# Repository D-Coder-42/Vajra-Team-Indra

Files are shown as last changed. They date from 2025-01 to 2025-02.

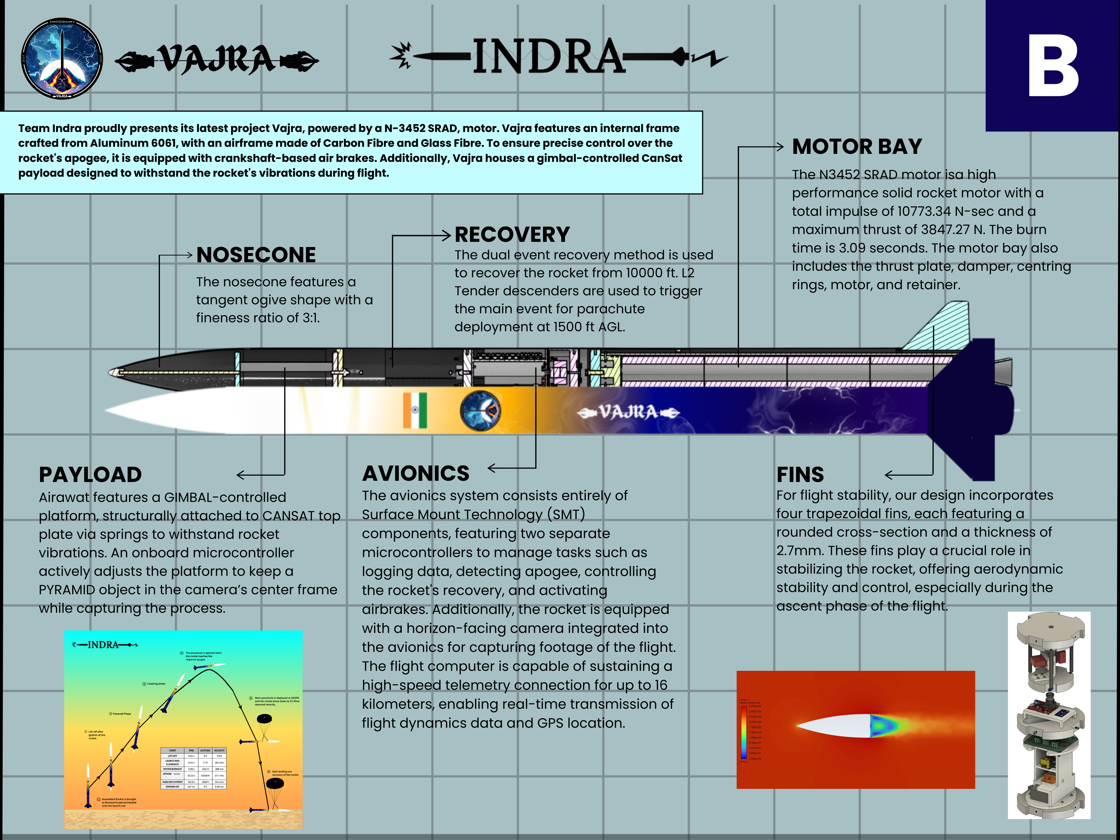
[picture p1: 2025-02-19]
Management/Poster Session.png

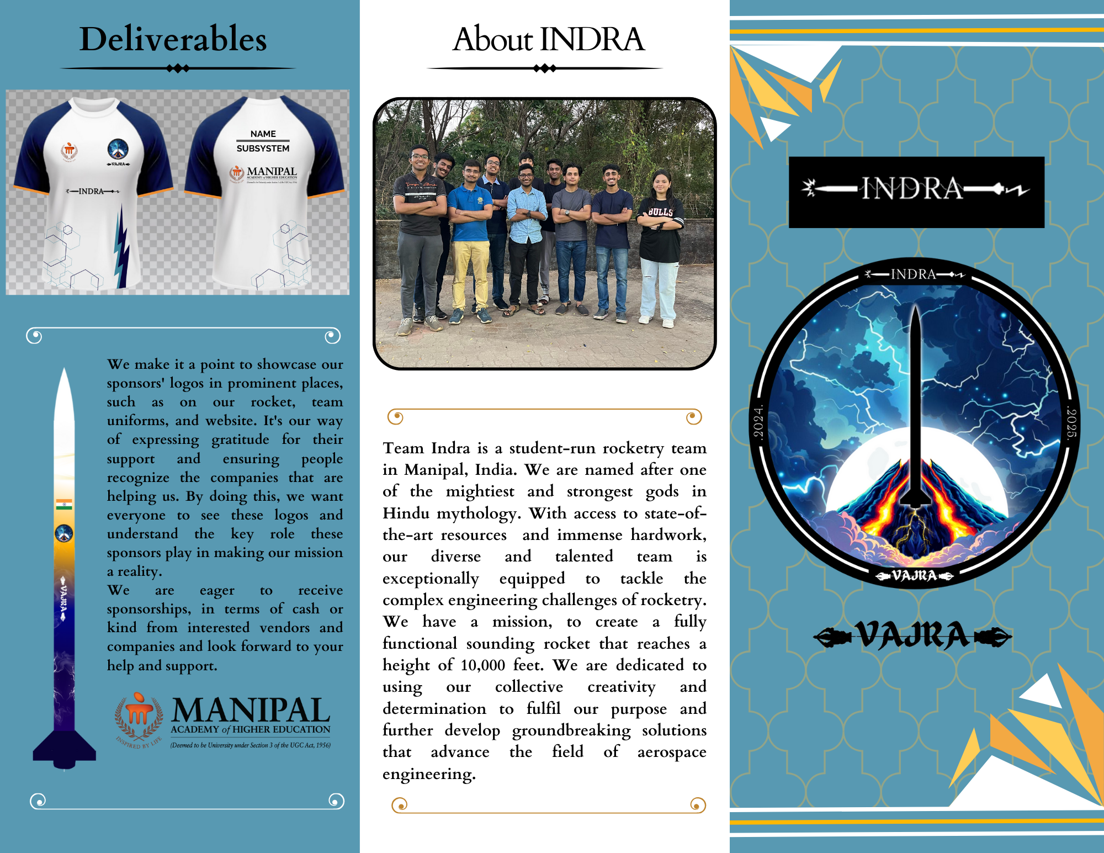
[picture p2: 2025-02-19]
Management/Brochure (Page 1).png

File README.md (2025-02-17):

# Project Vajra
## By Team Indra

### Table of Contents
- [Team Members](#team-members)
- [Abstract](#abstract)
- [Introduction](#introduction)
- [Goals](#goals)

### Team Members
- **Shaurya Mittal** - Aerodynamics Member
- **Shaunak Purkayastha** - Propulsion Member
- **Tushit Chatterjee** - Structures Member
- **Krishanu Dey** - Avionics Member
- **Dhruv Phalod** - Avionics Member
- **Vanshdeep Trivedi** - Avionics Member
- **Mutra Sai Tharun** - Payload Member
- **Rudra Rajpurohit** - Payload Member
- **Swaraa Sule** - Management Member
- **Adithya Adiga** - Management Member

### Project Abstract
Team Indra’s rocket, Vajra, is powered by an N3452 N-class SRAD rocket motor. Its internal frame is made from Aluminum 6061, and the aerodynamic structure combines Carbon Fibre and Glass Fibre for optimal performance. The nosecone houses a CanSat payload with a GIMBAL-controlled platform, attached via springs to withstand rocket vibrations. An onboard microcontroller ensures the platform is positioned to keep a PYRAMID object aligned with the camera’s center for tracking the entire flight. The avionics use Surface Mount Technology (SMT) components, with two microcontrollers handling tasks like data logging, apogee detection, recovery control, and airbrake activation. The flight computer supports real-time telemetry up to 16 kilometers, transmitting flight dynamics and GPS data.

### Team Introduction
Team Indra is a student-run rocketry team based in Manipal, India. We are named after one of the mightiest and strongest gods in Hindu mythology. With access to state-of-the-art resources and immense hard work, our diverse and talented team is exceptionally equipped to tackle the complex engineering challenges of rocketry. Our mission is to create a fully functional sounding rocket that reaches a height of 10,000 feet. We are dedicated to using our collective creativity and determination to fulfill our purpose and further develop groundbreaking solutions that advance the field of aerospace engineering.

### Goals
- Develop a fully functional sounding rocket.
- Achieve a flight altitude of 10,000 feet.
- Innovate in the fields of aerodynamics, propulsion, and avionics.

###
All codes and files for Team B of thrustMIT subscale are included in this repository.

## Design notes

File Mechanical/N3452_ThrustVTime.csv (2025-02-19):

Time(s) | Thrust(N)
0 | 0
0.03 | 2930.23055
0.06 | 2946.55281
0.09 | 2962.75934
0.12 | 2978.84899
0.15 | 2994.82061
0.18 | 3010.6731
0.21 | 3026.40532
0.24 | 3042.01619
0.27 | 3057.5046
0.3 | 3072.86948
0.33 | 3088.10975
0.36 | 3103.22435
0.39 | 3118.21222
0.42 | 3133.07234
0.45 | 3147.80367
0.48 | 3162.40519
0.51 | 3176.87589
0.54 | 3191.21478
0.57 | 3205.42087
0.6 | 3219.49318
0.63 | 3233.43075
0.66 | 3247.23263
0.69 | 3260.89786
0.72 | 3274.42552
0.75 | 3287.81469
0.78 | 3301.06445
0.81 | 3314.17391
0.84 | 3327.14217
0.87 | 3339.96836
0.9 | 3352.6516
0.93 | 3365.19104
0.96 | 3377.58584
0.99 | 3389.83515
1.02 | 3401.93816
1.05 | 3413.89405
1.08 | 3425.70201
1.11 | 3437.36127
1.14 | 3448.87102
1.17 | 3460.23051
1.2 | 3471.43898
1.23 | 3482.49568
1.26 | 3493.39986
1.29 | 3504.15081
1.32 | 3514.74781
1.35 | 3525.19016
1.38 | 3535.47716
1.41 | 3545.60812
1.44 | 3555.58239
1.47 | 3565.3993
1.5 | 3575.05819
1.53 | 3584.55844
1.56 | 3593.89941
1.59 | 3603.0805
1.62 | 3612.10109
1.65 | 3620.96058
1.68 | 3629.65841
1.71 | 3638.19399
1.74 | 3646.56677
1.77 | 3654.7762
1.8 | 3662.82174
1.83 | 3670.70285
1.86 | 3678.41904
1.89 | 3685.96978
1.92 | 3693.35459
1.95 | 3700.57299
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

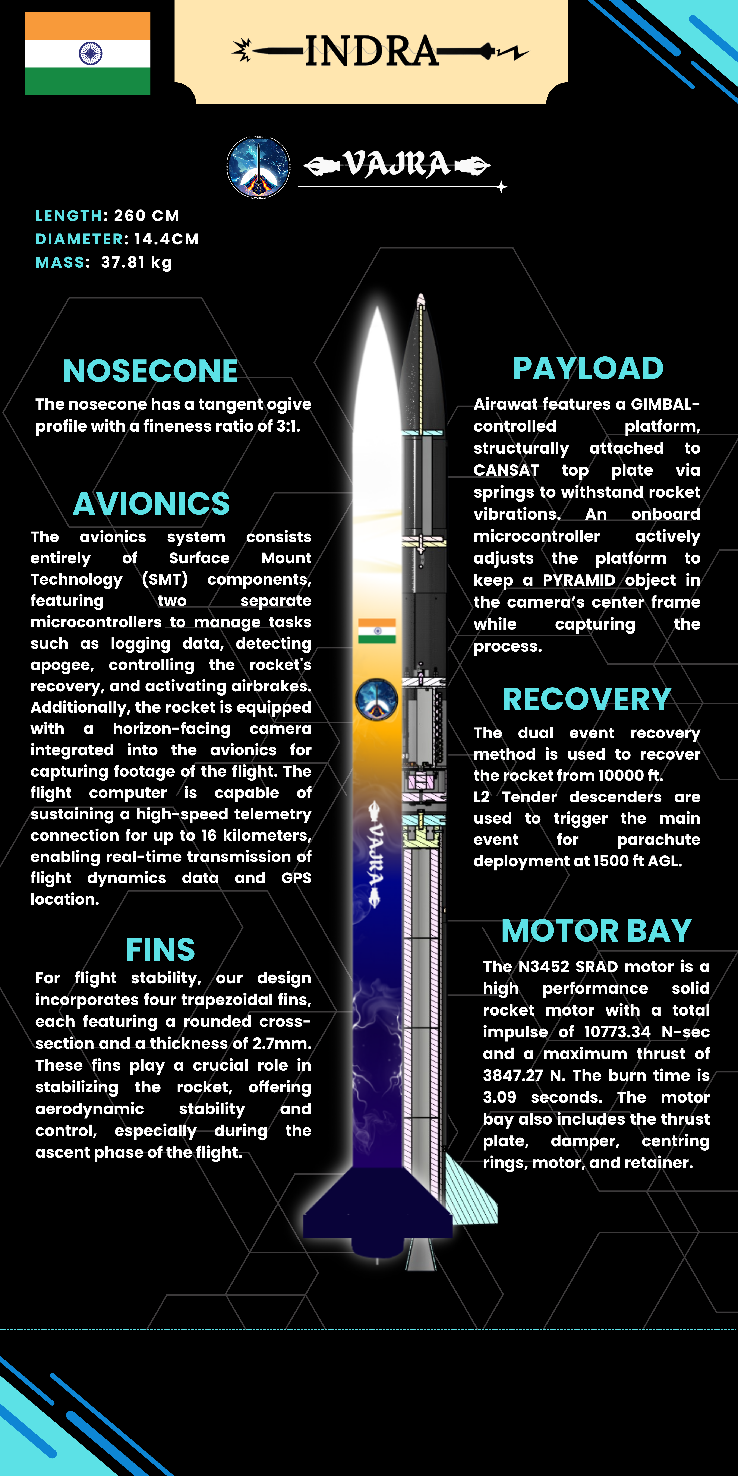
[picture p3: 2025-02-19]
Management/Con-Ops Poster.png

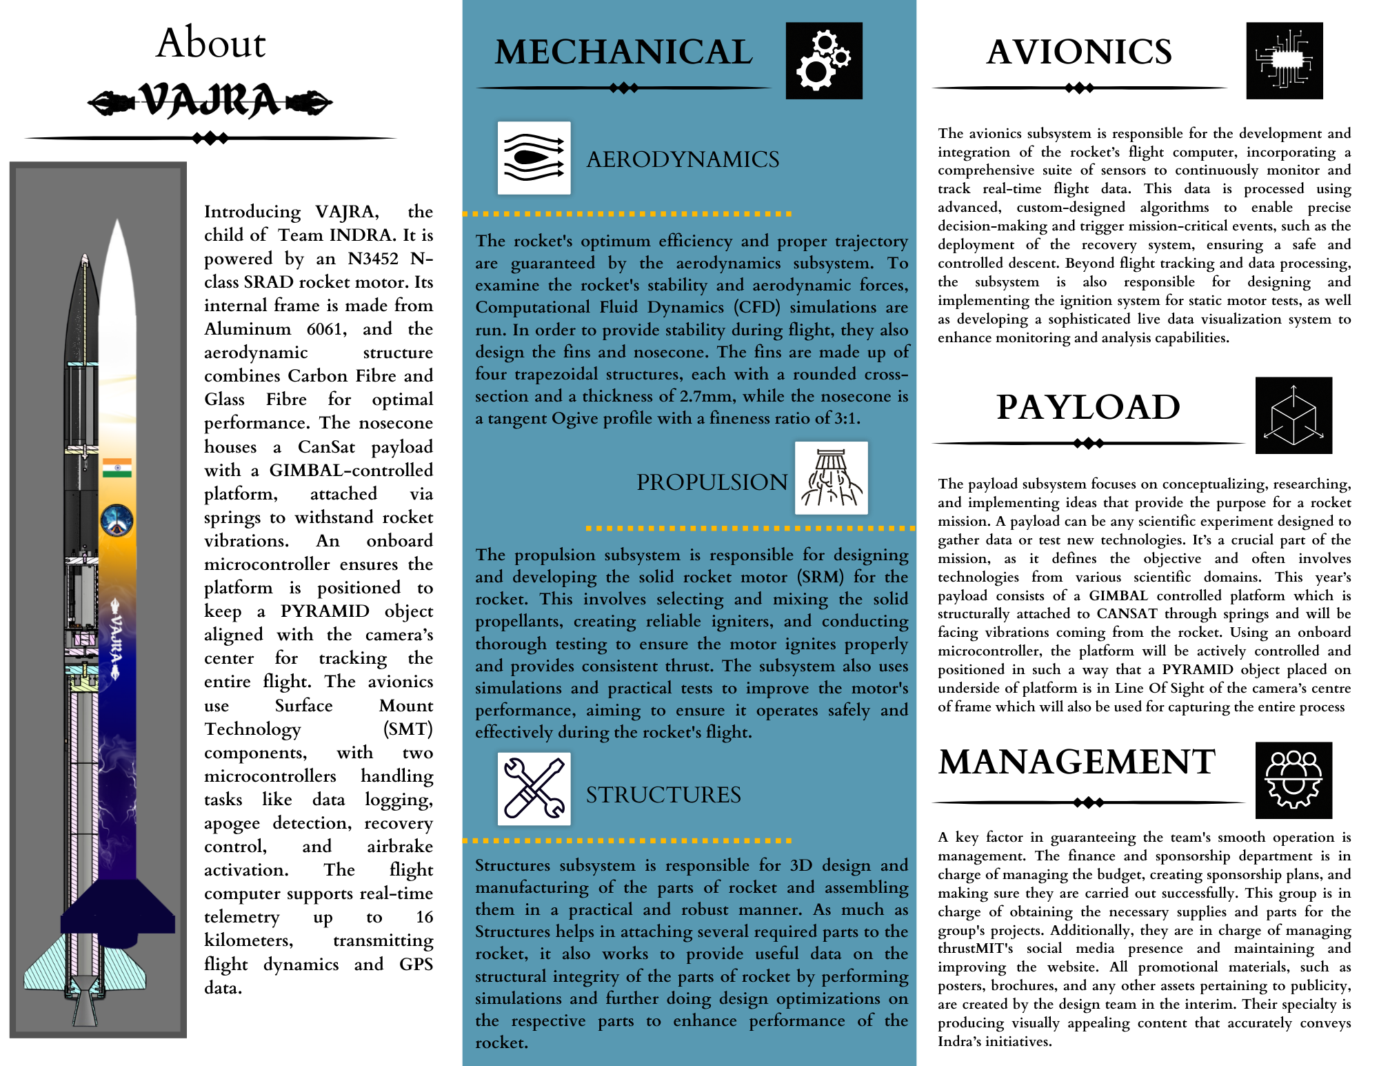
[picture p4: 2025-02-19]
Management/Brochure (Page 2).png

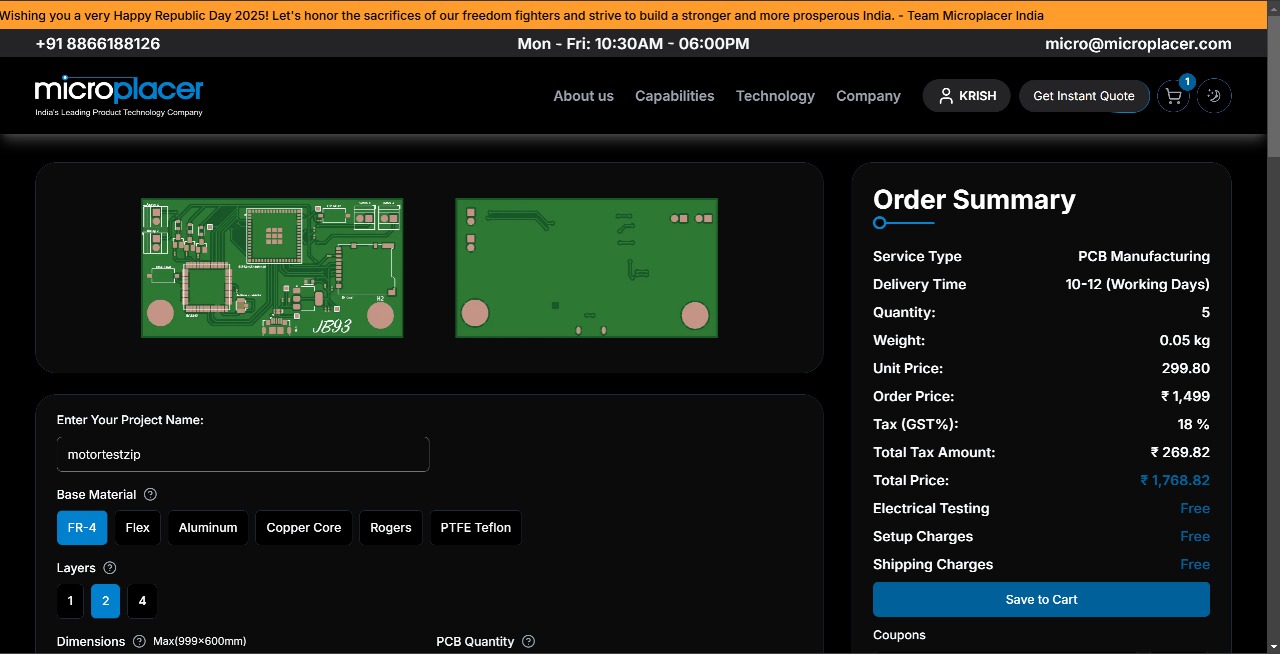
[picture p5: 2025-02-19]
Avionics/Ignition System PCB/JB93_QUOTATION.jpg

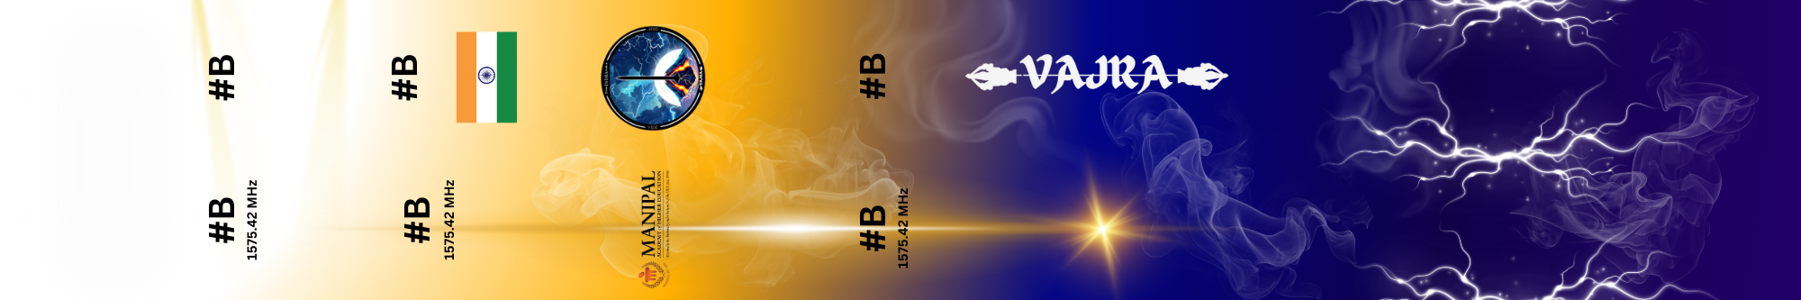
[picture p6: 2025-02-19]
Management/Rocket Decal.png

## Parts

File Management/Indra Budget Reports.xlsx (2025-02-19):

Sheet: Budget Report
ltems | Vendor Name | Quantity Required | Subsystem | Unit Price (INR) | Total Amount (INR)
Kevlar Shock Cord | https://www.apogeerockets.com/Building_Supplies/Parachutes_Recovery_Equipment/Shock_Cord/Kevlar_Cord_300 | 22 units | Aerodynamics | 352 | 7744
24" Compact Elliptical Parachute | https://shop.fruitychutes.com/collections/parachutes/products/24-compact-elliptical-parachute-2-1lb-20fps | 1 unit | Aerodynamics | 6828 | 6828
Iris UltraLight 66" Parachute | https://shop.fruitychutes.com/collections/iris-ultralight-parachutes/products/iris-66-ultra-light-parachute-13-6lb-15fps | 1 unit | Aerodynamics | 29708 | 29708
1515 Rail Buttons | https://shop.fruitychutes.com/products/1515-rail-button-pair-of-2 | 1 Pair | Aerodynamics | 350 | 350
L2 tender Descenders | https://www.apogeerockets.com/Building-Supplies/Recovery-Equipment/Tether-Release-Devices/TD-2-Tether-and-Release-Device | 2 | Aerodynamics | 9957 | 19914
MPXV5100DP | https://in.element14.com/nxp/mpxv5100dp/pressure-sensor-dual-14-5-psi/dp/1608912 | 2 | Avionics | 1462 | 2924
ESP32 S3 WROOM 1U | https://robu.in/product/espressif-esp32-s3-wroom-1u-n16r8-module/ | 2 | Avionics | 299 | 598
ESP32 S3 MINI 1U | https://www.digikey.in/en/products/detail/espressif-systems/ESP32-S3-MINI-1U-N8/17728863 | 4 | Avionics | 267.44 | 1069.76
IIM-42653 | https://www.digikey.in/en/products/detail/tdk-invensense/IIM-42653/22477277 | 2 | Avionics | 489.8 | 979.6
LPS22HHTR | https://robu.in/product/stmicroelectronics-lps22hhtr26kpa126kpa-1-7v3-6v-40%e2%84%8385%e2%84%83/ | 2 | Avionics | 312 | 624
D3V3XA4B10LP | https://www.digikey.in/en/products/detail/diodes-incorporated/D3V3XA4B10LP-7/10295141 | 6 | Avionics | 24.16 | 144.96
Micro SD connector SMD | https://in.element14.com/hirose-hrs/dm3bt-dsf-pejs/connector-micro-sd-push-push-smt/dp/1764375 | 4 | Avionics | 194.81 | 779.24
AMS11177-3.3V | https://robu.in/product/ams1117-3-3v-1a-sot-223-voltage-regulator-ic-pack-of-5-ics/ | 10 | Avionics | 11 | 110
M20050-1 | https://www.digikey.in/en/products/detail/antenova/M20050-1/7931499 | 2 | Avionics | 2037.84 | 4075.68
USB port | https://in.element14.com/gct-global-connector-technology/usb3076-30-a/micro-usb-2-0-type-b-receptacle/dp/2443117 | 6 | Avionics | 59.28 | 355.68
AMS1117-5V | https://robu.in/product/ams1117-5-0v-1a-sot-223-voltage-regulator-ic-pack-of-5-ics/ | 5 | Avionics | 5.2 | 26
Solder Kit | https://robu.in/product/plusivo-soldering-kit-with-diagonal-wire-cutter/ | 1 | Avionics | 1365 | 1365
IRLR7843TRPBF | https://robu.in/product/irlr7843trpbf-mosfet/ | 4 | Avionics | 128 | 512
RYLR993 | https://robu.in/product/reyax-rylr993-868-915mhz-lorawan-transceiver-module/ | 4 | Avionics | 1099 | 4396
Camera | https://robu.in/product/runcam-split-3-nano-hd-fpv-camera/ | 1 | Avionics | 5642 | 5642
LEDs | https://robu.in/product/0805-surface-mount-led-red-50-pcs/ | 10 | Avionics | 2 | 20
LEDs | https://robu.in/product/0805-surface-mount-led-green-50-pcs/ | 10 | Avionics | 2 | 20
LEDs | https://robu.in/product/0805-surface-mount-led-blue-50-pcs/ | 10 | Avionics | 2 | 20
Push button | https://robu.in/product/362-5mm-tactile-push-button-switch-20pcs/ | 6 | Avionics | 10 | 60
Desolder wick | https://robu.in/product/desoldering-wick-1-5m-100-copper/ | 1 | Avionics | 149 | 149
Pyro Batteries | https://robu.in/product/molicel-inr18650-p28a-2800mah-13c-lithium-ion-battery/ | 4 | Avionics | 434 | 1736
Main batteries | https://robu.in/product/molicel-inr-18650-m35a-3-6v-3500mah-3c-li-ion-battery/ | 7 | Avionics | 499 | 3493
Featherweight GPS (incl Shipping + customs) | https://www.featherweightaltimeters.com/store/p22/Featherweight_GPS_Tracker_%28upd%29.html | 1 | Avionics | 31547.99 | 31547.99
EasyMini (incl Shipping + Customs) | https://www.apogeerockets.com/Electronics-Payloads/Dual-Deployment/EasyMini | 1 | Avionics | 13015.48 | 13015.48
2 x 1 Battery holders | https://robu.in/product/18650-dual-smd-smt-high-quality-single-battery-holder/ | 3 | Avionics | 76 | 228
1 x 1 Battery holders | https://robu.in/product/18650-battery-holder-smd-smt/ | 3 | Avionics | 31 | 93
SMA to UFL.R connector | https://robu.in/product/lwc-ca-sma-jack-bh-st-ufl-1-13mm-rf-cable-assemblies-15cm/?gad_source=1 | 3 | Avionics | 69 | 207
900MHz Antenna | https://robu.in/product/698-960-mhz-1710-2690-mhz-5dbi-gain-dual-band-3g-4g-lte-antenna/?gad_source=1 | 3 | Avionics | 199 | 597
Digital Multimeter | https://robu.in/product/htc-830l-digital-multimeter/ | 1 | Avionics | 585 | 585
Prototyping board | https://robu.in/product/9-x-15-cm-universal-pcb-prototype-board-single-sided-2-54mm-hole-pitch/ | 1 | Avionics | 80 | 80
Pressure Transducer | https://robu.in/product/30mpa-stainless-steel-pressure-transducer-sensor-copy/ | 1 | Avionics | 2585 | 2585
IRLB8314 | https://in.element14.com/infineon/irlb8314pbf/mosfet-n-channel-30v-171a-to-220ab/dp/2617411 | 5 | Avionics | 111.05 | 555.25
Servo | https://probots.co.in/servo-ds5160-60kg-270-degrees-high-torque-high-speed-digital-steering-gear.html | 1 | Avionics | 4999 | 4999
22AWG Wires (Red) | https://robu.in/product/high-quality-ultra-flexible-22awg-silicone-wire-1000m-red/ | 15 | Avionics | 18 | 270
100 nF Capacitor | https://robu.in/product/c2012x7r1h104kt0j0n-tdk-50v-100nf-x7r%C2%B110-0805-multilayer-ceramic-capacitors-mlcc-smd-smt-rohs/ | 36 | Avionics | 2 | 72
10nF Capacitor | https://robu.in/product/c2012c0g1h103jt000n-tdk-50v-10nf-c0g%C2%B15-0805-multilayer-ceramic-capacitors-mlcc-smd-smt-rohs/ | 2 | Avionics | 4 | 8
10uF Capacitor | https://robu.in/product/0805b106k160nt-fh-16v-10uf-x7r%C2%B110-0805-multilayer-ceramic-capacitors-mlcc-smd-smt-rohs/ | 16 | Avionics | 4 | 64
1uF Capacitor | https://robu.in/product/c2012x7r1c105kt000n-tdk-16v-1uf-x7r%C2%B110-0805-multilayer-ceramic-capacitors-mlcc-smd-smt-rohs/ | 2 | Avionics | 4 | 8
2.2uF Capacitor | https://robu.in/product/0805x225k500nt-fh-50v-2-2uf-x5r%C2%B110-0805-multilayer-ceramic-capacitors-mlcc-smd-smt-rohs/ | 4 | Avionics | 1.86 | 7.44
22pF Capacitor | https://robu.in/product/0805n220j101ct-walsin-cap-smd-mlcc-22-pf-100-v-0805-pack-of-5/ | 2 | Avionics | 19 | 38
22uF Capacitor | https://robu.in/product/0805x226m250nt-fh-25v-22uf-x5r%C2%B120-0805-multilayer-ceramic-capacitors-mlcc-smd-smt-rohs/ | 6 | Avionics | 4 | 24
22 Ohm Resistor | https://robu.in/product/rc0805fr-0722rl-yageo-smd-chip-resistor-22-ohm-%C2%B1-1-125-mw-0805-2012-metric-thick-film-general-purpose/ | 4 | Avionics | 1 | 4
220 Ohm Resistor | https://robu.in/product/rc0805fr-07220rlyageores-smd-220-ohm-5-1-2w-0805/ | 10 | Avionics | 0.35 | 3.5
10 kOhm Resistor | https://robu.in/product/rc0805fr-0710kl-yageo-res-thick-film-0805-10k-ohm-1-0-125w1-8w-%C2%B1100ppm-c-pad-smd-t-r/ | 6 | Avionics | 0.35 | 2.1
1 kOhm Resistor | https://robu.in/product/ac0805fr-071kl-yageo-res-thick-film-0805-1k-ohm-1-0-125w1-8w-%C2%B1100ppm-c-pad-smd-t-r-automotive-aec-q200/ | 8 | Avionics | 0.72 | 5.76
4.7 kOhm Resistor | https://robu.in/product/ac0805fr-074k7l-yageo-res-thick-film-0805-4-7k-ohm-1-0-125w1-8w-%C2%B1100ppm-c-pad-smd-t-r-automotive-aec-q200/ | 4 | Avionics | 0.72 | 2.88
0 Ohm Resistor | https://robu.in/product/ac0805jr-070rl-yageo-res-thick-film-0805-0-ohm-pad-smd-t-r-automotive-aec-q200/?gQT=1 | 2 | Avionics | 0.25 | 0.5
1.8 nH Inductor | https://robu.in/product/vhf201209h1n8st-fh-500ma-1-8nh-%C2%B10-3nh-o-1%CF%89-0805-inductors-smd-rohs/ | 2 | Avionics | 6 | 12
47nH Inductor | https://robu.in/product/47nh-5-300ma-0805-surface-mount-high-frequency-inductor-vhf201209h47njt-pack-of-10/ | 4 | Avionics | 5 | 20
22AWG Wires (Black) | https://robu.in/product/high-quality-ultra-flexible-22awg-silicone-wire-1000m-black/ | 15 | Avionics | 18 | 270
22AWG Wires (Blue) | https://robu.in/product/1000-meter-ul1007-22awg-pvc-electronic-wire-blue/ | 10 | Avionics | 10 | 100
24AWG Wires | https://robu.in/product/high-quality-ultra-flexible-24awg-silicone-wire-1000m-blue/ | 8 | Avionics | 9 | 72
UFL port SMD | https://www.digikey.in/en/products/detail/hirose-electric-co-ltd/U-FL-R-SMT-1-10/2391570 | 2 | Avionics | 103.52 | 207.04
PCB Manufacturing-Flight computer | Microplacer | 1 | Avionics | 1985.14 | 1985.14
PCB Manufacturing-Ignition system | Microplacer | 1 | Avionics | 1768.82 | 1768.82
Load Cell Amplifier | https://samyak.co.in/products/load-cell-amplifier/ | 1 | Avionics | 3445 | 3445
Pitot Tube | https://www.flyrobo.in/pitot-tube-for-pixhawk-air-speed-sensor?tracking=ads | 2 | Avionics | 394 | 788
battery for servo | https://robu.in/product/ncr18650ga-7-4v-7000mah-2s2pin-a-line-3c-li-ion-battery-pack/?gad_source=1 | 1 | Avionics | 2702 | 2702
wire stripper | https://robu.in/product/wire-stripper-flat-nose-cable-cutter-with-practical-punch-down-tool/ | 2 | Avionics | 18 | 36
insulation tape | Pratham xerox | 1 | Avionics | 35 | 35
screw driver (star) | Pratham xerox | 1 | Avionics | 80 | 80
screw driver (flathead) | Pratham xerox | 1 | Avionics | 80 | 80
5.08mm screw terminal | https://robu.in/product/2-pin-5-08mm-pitch-pluggable-screw-terminal-block-pack-of-3/ | 3 | Avionics | 46 | 138
2.54mm screw terminal | https://robu.in/product/2-pin-2-54mm-pitch-pluggable-screw-terminal-block-pack-of-3/ | 3 | Avionics | 46 | 138
1tf load cell | https://adiartech.com/load-cells/ | 1 | Avionics | 20000 | 20000
Chair | https://www.flipkart.com/blapoxe-portable-folding-camping-chair-arm-rest-cup-holder-carrying-storage-bag-dark-blue-pack-2-metal-outdoor/p/itm17bbe6a8fa746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 | 6 | Management | 874.5 | 5247
Tent | https://www.amazon.in/Waterproof-Gazebo-Outdoor-Terrace-Garden/dp/B0BWYHLJM1?hvadid=709962165341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 | 1 | Management | 5999 | 5999
Standing Poster | https://www.vistaprint.in/signs-posters/standees?swsquery=standing%20poste&querycat=search_dropdown | 2 | Management | 1750 | 3500
Brochure | https://www.vistaprint.in/marketing-materials/brochures | 50 | Management | 960 | 960
Technical Report Printouts | Campus Stores | 2 Sets | Management | 250 | 500
Decal | UR ART Gallery | 1 | Management | 2500 | 2500
Basic Stationery | Campus Stores | 1 | Management | 1000 | 1000
Board Pins | Campus Stores | 1 box | Management | 100 | 100
Walkie Talkies | https://www.industrybuying.com/walkie-talkie-renmax-ITE.WAL.724159543?gad_source=1 | Set of 4 | Management | 5073 | 5073
KST Servo DS215MG V8.0 | https://robu.in/product/kst-servo-ds215mg-v8-0/ | 2 | Payload | 3549 | 7098
Teensy 4.1 | https://robu.in/product/buy-teensy-4-1-development-board/?gad_source=1 | 1 | Payload | 2639 | 2639
Resistor THT (RHC2512FT220R) | https://www.digikey.in/en/products/detail/stackpole-electronics-inc/RHC2512FT220R/1646043 | 10 | Payload | 5.9 | 59
LED SMD (HSMC-C170) | https://www.digikey.in/en/products/detail/broadcom-limited/HSMC-C170/637689 | 10 | Payload | 3.1 | 31
OpenMV H7+ | https://robu.in/product/openmv-cam-h7-plus/ | 1 | Payload | 9192 | 9192
PDB-XT60 with BEC 5V and 12V | https://robu.in/product/pdb-xt60-w-bec-5v-12v/ | 1 | Payload | 297 | 297
MPU9250 9-Axis Attitude Gyro Accelerator Magnetometer Sensor Module | https://robu.in/product/mpu9250-9-axis-attitude-gyro-accelerator-magnetometer-sensor-module-2/?gad_source=1 | 2 | Payload | 430 | 860
Pro-Range INR 18650 P28A 7.4V 5600mAh 2S2P 60A/70A Discharge Li-ion Drone Battery Pack | https://robu.in/product/pro-range-inr-21700-p42a-7-4v-4200mah-2s1p-40a-50a-discharge-li-ion-drone-battery-pack/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 | 1 | Payload | 2549 | 4899
XY128VC-5.0-XINYA-2 Pin Screw Terminal Block(Green) | https://robu.in/product/xy128vc-5-0-xinya-2-pin-screw-terminal-blockgreen/?gad_source=1 | 8 | Payload | 11 | 88
SanDisk Micro SD/SDHC 32GB Class 10 Memory Card | https://robu.in/product/sandisk-micro-sd-sdhc-32gb-class-10-memory-card-with-adapter/?gad_source=1 | 1 | Payload | 419 | 419
80662SCS - 2 Inch 302/304 Stainless Steel Extension Spring | https://www.mwcomponents.com/shop/80662scs | 3 | Payload | 1035.5 | 3106.5
ISOCHEM Potassium Nitrate (5 KG) Assay 99% Min | ISOCHEM Laboratories | 4 box | Propulsion | 3900 | 3900
RTV Silicone | Anabond | 6 tubes | Propulsion | 1744 | 1744
Extrusions | RT Aluminium Profile |  | Propulsion | 5000 | 5000
IR Thermometer | https://robu.in/product/htc-mt-4-digital-non-contact-ir-infrared-thermometer-with-high-accuracy-temperature-range-50c550c-58f1022f/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 | 1 Unit | Propulsion | 1124 | 1124
Themisto Digital LCD Cooking Food Meat Probe Kitchen BBQ Thermometer Temperature Test Pen| Instant Read | https://www.amazon.in/THEMISTO-Digital-Cooking-Thermometer-Temperature/dp/B07TBGBMQS?hvadid=709972793905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 | 1 unit | Propulsion | 189 | 189
ECO SOUL [Set of 3] Bamboo Cooking Utensils | Non-Stick Wooden Spoons, Ladles & Turners | Bamboo Wood Kitchen Accessories for Cooking, Serving, Mixing | USDA Certified | https://www.amazon.in/ECO-SOUL-Utensils-Non-Stick-Certified/dp/B0BN87GM7V?th=1 | 1 unit | Propulsion | 251 | 251
PTR Heavy Base Big Black Iron Mathar Kadhai | Kadai with Handle for Kitchen | Deep Frying Kadai | Cooking Wok Pot for Kitchen (10 Litre) | https://www.amazon.in/PTR-Iron-Kadhai-Kitchen-Cooking/dp/B0CP7N7JXN?th=1 | 1 unit | Propulsion | 2499 | 2499
Induction Cooktop (Pigeon by Stovekraft Cruise 1800 watt Induction Cooktop With Crystal Glass,7 Segments LED Display, Auto Switch Off - Black | https://www.amazon.in/Pigeon-Stovekraft-Cruise-1800-Watt-Induction/dp/B01GFTEV5Y?th=1 | 1 unit | Propulsion | 1199 | 1199
Sorbitol (98% pure) | https://www.srlchem.com/product/details/7481/33320/D-Sorbitol-Powder-for-tissue-culture-98 | 20KG | Propulsion | 1100 | 22000
Measuring Tape | Manipal Hardware | 1 Unit | Structures/ Manufacturing | 150 | 150
Vernier Caliper | Manipal Hardware | 1 unit | Structures/ Manufacturing | 650 | 650
Angle Grinder (Wired) With Disk Set | https://robu.in/product/black-and-decker-angle-grinder-4-inch-820w-g720r/?gad_source=1 | 1 unit | Structures/ Manufacturing | 2050 | 2050
Duct Tape, Masking Tape, Cellotape | Manipal Hardware | 1 each | Structures/ Manufacturing | 300 | 300
Sand Paper (Grit: 60,150, 1000 and anything close to these numbers) | Manipal Hardware | 3 sheets of each grit | Structures/ Manufacturing | 133 | 1200
Pneumatic Drill Machine (Wired) With Drill bits | https://www.amazon.in/Bosch-GSB-500W-500-RE/dp/B00INTGY6O?hvadid=709855992702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 | 1 unit | Structures/ Manufacturing | 3699 | 3699
WD-40 | Manipal Hardware | 1 unit | Structures/ Manufacturing | 200 | 200
Stainless Steel 316 Block | Hi-Tech Sales Corporation Mangalore | 1 units | Structures/ Manufacturing | 30000 | 30000
Aluminium 6061 T6 sheet | Hi-Tech Sales Corporation Mangalore | 1units | Structures/ Manufacturing | 51875 | 51875
Aluminium 6061 T6 Block | Hi-Tech Sales Corporation Mangalore | 1 units | Structures/ Manufacturing | 22500 | 22500
Rounded head Bolts (M2, M3, M5, M6, M8) | Manipal Hardware | 100 pc. of each of the 4 sizes | Structures/ Manufacturing | 2000 | 4000
Vaccum Bag Film | https://www.carbonblackcomposites.in/product-page/vacuum-bagging-film | 1 Roll | Structures/ Manufacturing | 499 | 499
Aradur HY 5052 | Sree Industrial Composite Products | 1.9 Kg | Structures/ Manufacturing | 4700 | 9400
Araldite LY 5052 | Sree Industrial Composite Products | 5 Kg | Structures/ Manufacturing | 3500 | 17500
Mould Release Agent | https://www.carbonblackcomposites.in/product-page/pva-mould-release-agent | 450 grams | Structures/ Manufacturing | 275 | 275
Fiberglass 200 GSM 2*2 Twill Weave | https://www.carbonblackcomposites.in/product-page/fiberglass-cloth-200gsm | 5X1.25m | Structures/ Manufacturing | 737.29 | 737.29
Boric Powder | https://www.amazon.in/Santosh-Boric-Powder-Cockroach-Purpose/dp/B08GKZPG3C?gQT=1&th=1 | 400 grams | Structures/ Manufacturing | 199 | 199
Carbon Fiber 240 GSM 2*2 Twill Weave | https://www.carbonblackcomposites.in/product-page/carbon-fiber-fabric-2x2-twill-3k | 20X1m | Structures/ Manufacturing | 34322.03 | 34322.03
Cling Wrap | https://www.amazon.in/Ezee-Biodegradable-Multipurpose-Non-Stick-Microwave/dp/B0CLLCMLYH | 2 rolls | Structures/ Manufacturing | 209 | 400
Custom Charges (40%) (Products from FrutyChutes) |  |  | Others | 17078 | 17078
Shipping Charges (Products from FrutyChutes) |  |  | Others | 5022 | 5022
NOTE: ALL ITEMS INCLUDE COST OF SHIPPING AND CUSTOMS (IF ANY). SHIPPING AND CUSTOMS COST FOR FrutyChutes HAS BEEN ADDED IN "OTHERS IN ROW 120 AND 121.
Total Budget:
Aerodynamics | 64544
Avionics | 115979.82
Management | 24879
Payload | 28688.5
Propulsion | 37906
Structures/ Manufacturing | 179956.32
Others | 22100
Total Budget: | 474053.64
Average Cost | 3976.55
Maximum Amount | 51875
Minimum Amount | 0.5
Total Number of Components | 120
Legends | Amount
85 | Less than 3000
20 | 3000-7500
3 | 7500-12500
12 | Above 12500
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

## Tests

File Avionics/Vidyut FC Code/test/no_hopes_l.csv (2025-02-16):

time | pressure | altitude | velocity | acc_x | acc_y | acc_z | acc_tot
-4.68 | 98.5661 | -0.807 | 0 | 25.971 | -3.558 | -18.616 | 32.151
-4.66 | 98.5651 | -0.579 | 0 | 26.326 | -3.558 | -18.112 | 32.153
-4.64 | 98.5667 | -0.76 | 0 | 26.326 | -3.558 | -18.112 | 32.153
-4.62 | 98.5635 | -0.331 | 0 | 26.149 | -3.38 | -18.112 | 31.988
-4.6 | 98.5672 | -0.304 | 0 | 26.326 | -3.558 | -18.364 | 32.295
-4.58 | 98.5672 | -0.655 | 0 | 26.149 | -3.736 | -18.364 | 32.171
-4.56 | 98.5672 | -0.591 | 0 | 26.326 | -3.558 | -18.112 | 32.153
-4.54 | 98.5661 | -0.303 | 0 | 26.326 | -3.558 | -18.364 | 32.295
-4.52 | 98.5651 | 0.097 | 0 | 26.149 | -3.736 | -18.112 | 32.028
-4.5 | 98.5687 | -0.417 | 0 | 26.149 | -3.38 | -18.364 | 32.131
-4.48 | 98.5672 | -0.38 | 0 | 26.326 | -3.558 | -18.112 | 32.153
-4.46 | 98.5625 | -0.235 | 0 | 26.504 | -3.736 | -18.112 | 32.319
-4.44 | 98.5646 | -0.008 | 0 | 26.326 | -3.558 | -18.112 | 32.153
-4.42 | 98.562 | 0.442 | 0 | 26.326 | -3.558 | -18.112 | 32.153
-4.4 | 98.5604 | 1.117 | 0 | 26.326 | -3.558 | -18.364 | 32.295
-4.38 | 98.5625 | 0.797 | 0 | 26.326 | -3.558 | -18.364 | 32.295
-4.36 | 98.564 | 0.466 | 0 | 26.326 | -3.558 | -18.364 | 32.295
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

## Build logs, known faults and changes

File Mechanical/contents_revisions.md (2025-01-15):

## Aerodynamics
### 1. [ORK Design (v1)](CubeSat_ORK_v1.ork)

   - Motor: M6400
   - Payload: 4 kg CubeSat
   - Stability: 1.74 cal
   - Apogee: 3239 m

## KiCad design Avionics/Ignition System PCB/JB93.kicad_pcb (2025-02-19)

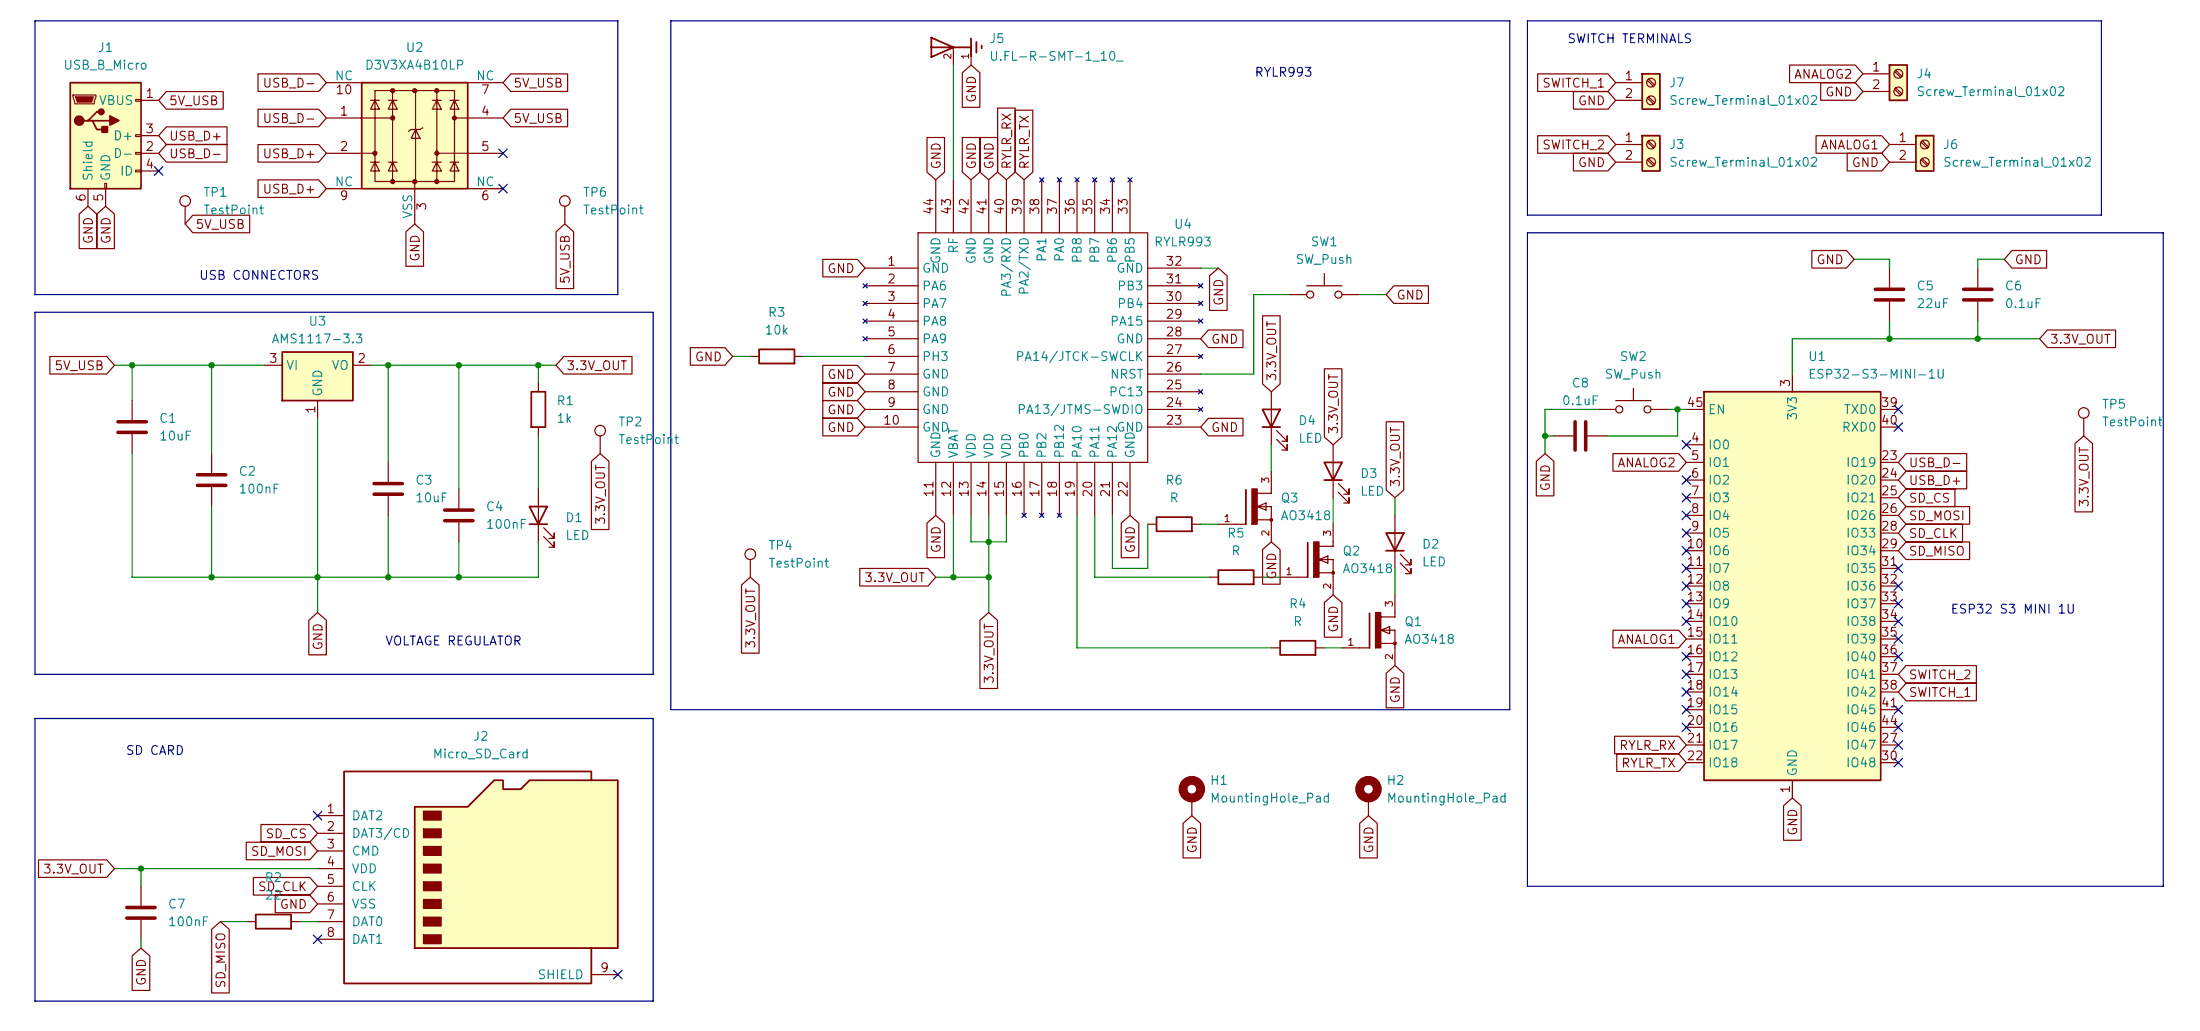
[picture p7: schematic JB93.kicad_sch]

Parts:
C1, C3: 10uF; C_0201_0603Metric
C2, C4, C7: 100nF; C_0201_0603Metric
C5: 22uF; C_0201_0603Metric
C6, C8: 0.1uF; C_0201_0603Metric
D1, D2, D3, D4: LED; LED_miniPLCC_2315
H1, H2: MountingHole_Pad; MountingHole_4.3mm_M4_DIN965_Pad
J1: USB_B_Micro; USB_Micro-B_GCT_USB3076-30-A
J2: Micro_SD_Card; microSD_HC_Hirose_DM3BT-DSF-PEJS
J3, J4, J6, J7: Screw_Terminal_01x02; TerminalBlock_Xinya_XY308-2.54-2P_1x02_P2.54mm_Horizontal
J5: U.FL-R-SMT-1_10_; U.FL_Hirose_U.FL-R-SMT-1_Vertical
Q1, Q2, Q3: AO3418; SOT-23
R1: 1k; R_0201_0603Metric
R2: 22; R_0201_0603Metric
R3: 10k; R_0201_0603Metric
R4, R5, R6: R; R_0201_0603Metric
SW1, SW2: SW_Push; SW_Tactile_SPST_NO_Straight_CK_PTS636Sx25SMTRLFS
TP1, TP2, TP4, TP5, TP6: TestPoint; TestPoint_Pad_1.0x1.0mm
U1: ESP32-S3-MINI-1U; ESP32-S2-MINI-1U
U2: D3V3XA4B10LP; Diodes_UDFN-10_1.0x2.5mm_P0.5mm
U3: AMS1117-3.3; SOT-223-3_TabPin2
U4: RYLR993

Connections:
3.3V_OUT: C3.1, C4.1, C5.2, C6.2, C7.1, D2.2 (A), D3.2 (A), D4.2 (A), J2.4 (VDD), R1.1, TP2.1, TP4.1, TP5.1, U1.3 (3V3), U3.2 (VO), U4.12 (VBAT), U4.13 (VDD), U4.14 (VDD), U4.15 (VDD)
5V_USB: C1.1, C2.1, J1.1 (VBUS), TP1.1, TP6.1, U2.4, U2.7 (NC), U3.3 (VI)
ANALOG1: J6.1, U1.15 (IO11)
ANALOG2: J4.1, U1.5 (IO1)
GND: C1.2, C2.2, C3.2, C4.2, C5.1, C6.1, C7.2, C8.1, D1.1 (K), H1.1, H2.1, J1.5 (GND), J1.6 (Shield), J2.6 (VSS), J3.2, J4.2, J5.1, J6.2, J7.2, Q1.2, Q2.2, Q3.2, R3.1, SW1.2, SW2.1, U1.1 (GND), U1.2 (GND), U1.42 (GND), U1.43 (GND), U1.46 (GND), U1.47 (GND), U1.48 (GND), U1.49 (GND), U1.50 (GND), U1.51 (GND), U1.52 (GND), U1.53 (GND), U1.54 (GND), U1.55 (GND), U1.56 (GND), U1.57 (GND), U1.58 (GND), U1.59 (GND), U1.60 (GND), U1.61 (GND), U1.62 (GND), U1.63 (GND), U1.64 (GND), U1.65 (GND), U2.3 (VSS), U2.8 (VSS), U3.1 (GND), U4.1 (GND), U4.7 (GND), U4.8 (GND), U4.9 (GND), U4.10 (GND), U4.11 (GND), U4.22 (GND), U4.23 (GND), U4.28 (GND), U4.32 (GND), U4.41 (GND), U4.42 (GND), U4.44 (GND)
unnamed: D1.2 (A), R1.2
unnamed: D2.1 (K), Q1.3
unnamed: D3.1 (K), Q2.3
unnamed: D4.1 (K), Q3.3
unnamed: J2.7 (DAT0), R2.2
unnamed: Q1.1, R4.2
unnamed: Q2.1, R5.2
unnamed: Q3.1, R6.2
unnamed: C8.2, SW2.2, U1.45 (EN)
unnamed: SW1.1, U4.26 (NRST)
unnamed: R4.1, U4.19 (PA10)
unnamed: R5.1, U4.20 (PA11)
unnamed: R6.1, U4.21 (PA12)
unnamed: R3.2, U4.6 (PH3)
unnamed: J5.2, U4.43 (RF)
RYLR_RX: U1.21 (IO17), U4.40 (PA3/RXD)
RYLR_TX: U1.22 (IO18), U4.39 (PA2/TXD)
SD_CLK: J2.5 (CLK), U1.28 (IO33)
SD_CS: J2.2 (DAT3/CD), U1.25 (IO21)
SD_MISO: R2.1, U1.29 (IO34)
SD_MOSI: J2.3 (CMD), U1.26 (IO26)
SWITCH_1: J7.1, U1.38 (IO42)
SWITCH_2: J3.1, U1.37 (IO41)
USB_D+: J1.3 (D+), U1.24 (IO20), U2.2, U2.9 (NC)
USB_D-: J1.2 (D-), U1.23 (IO19), U2.1, U2.10 (NC)

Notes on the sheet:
VOLTAGE REGULATOR
SD CARD
RYLR993
USB CONNECTORS
SWITCH TERMINALS
ESP32 S3 MINI 1U

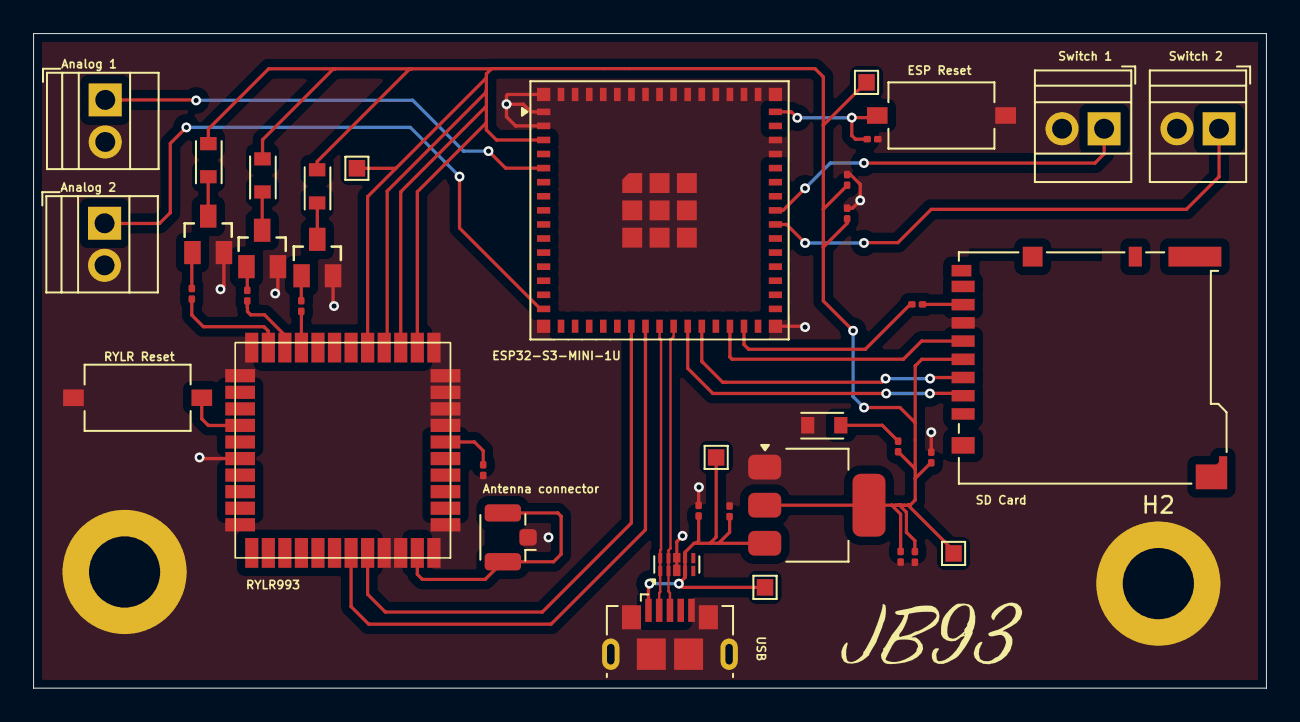
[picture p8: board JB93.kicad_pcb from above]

Board: 2 copper layers, 74.5 x 39.5 mm, 41 parts (0 on the bottom side), 30 nets.

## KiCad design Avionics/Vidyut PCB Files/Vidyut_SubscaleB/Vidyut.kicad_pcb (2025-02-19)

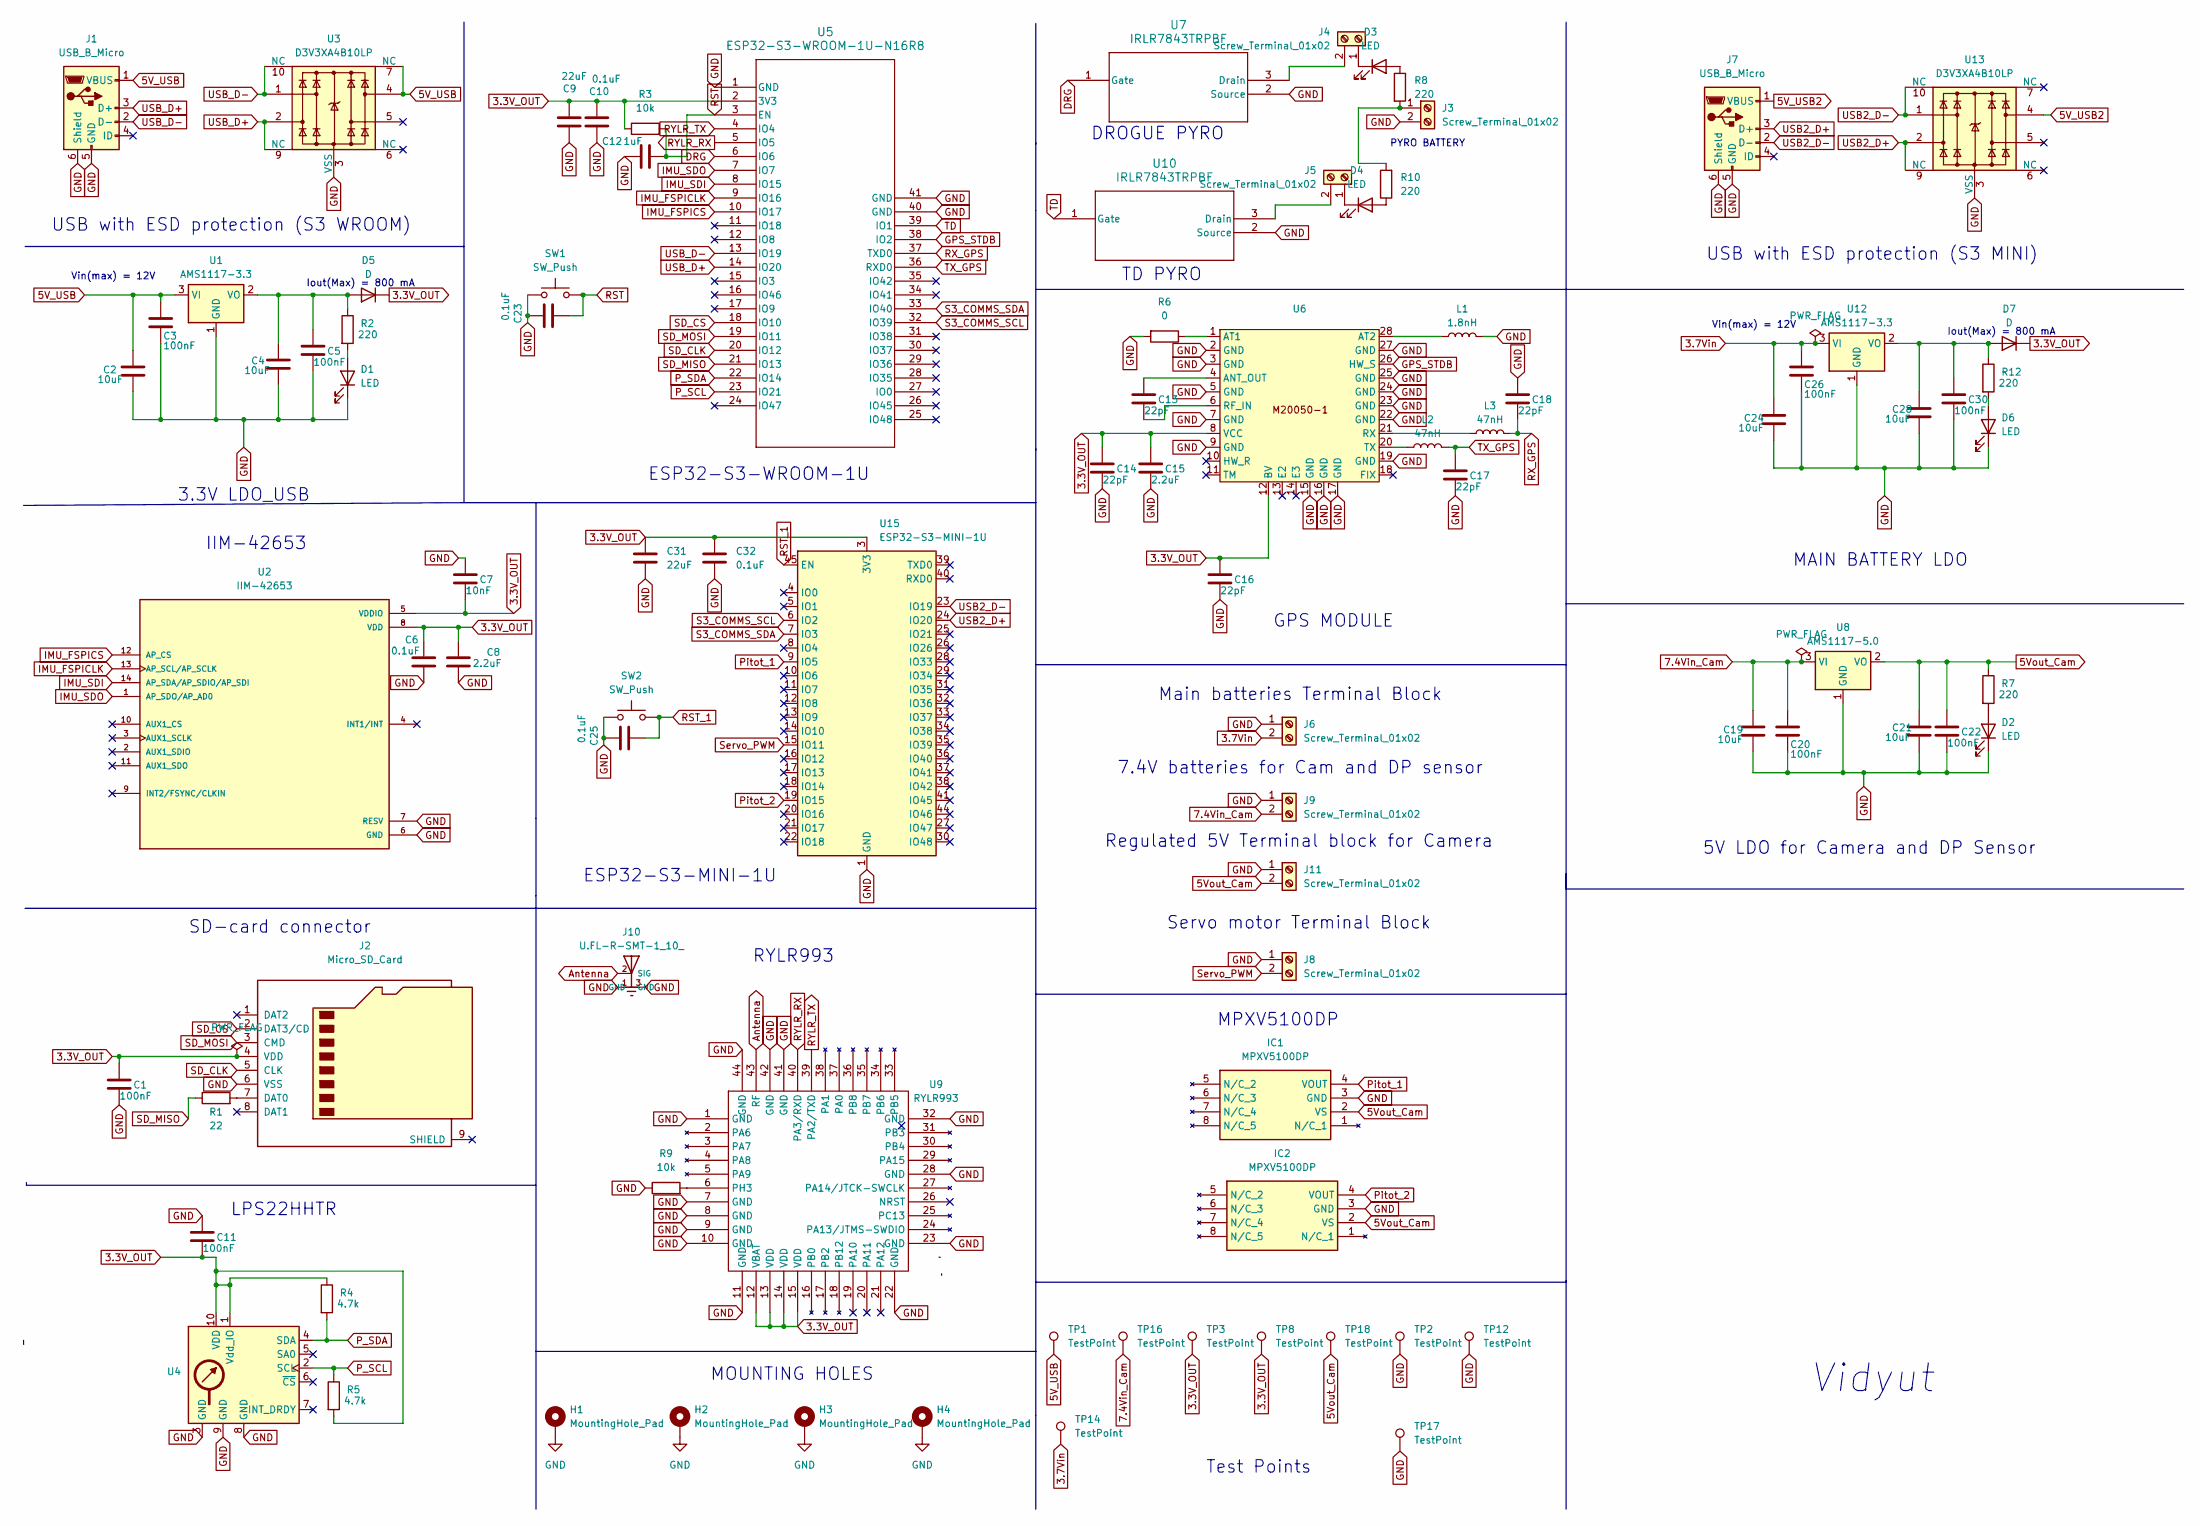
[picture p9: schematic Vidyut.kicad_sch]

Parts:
C1, C3, C5, C11, C20, C22, C26, C30: 100nF; C_0805_2012Metric
C2, C4, C19, C21, C24, C28: 10uF; C_0805_2012Metric
C6, C10, C23, C25, C32: 0.1uF; C_0805_2012Metric
C7: 10nF; C_0805_2012Metric
C8, C15: 2.2uF; C_0805_2012Metric
C9, C31: 22uF; C_0805_2012Metric
C12: 1uF; C_0805_2012Metric
C13, C14, C16, C17, C18: 22pF; C_0805_2012Metric
D1, D2, D3, D4, D6: LED; LED_0805_2012Metric
D5, D7: D; D_0805_2012Metric
H1, H2, H3, H4: MountingHole_Pad; MountingHole_4.3mm_M4_DIN965_Pad
IC1, IC2: MPXV5100DP; Manufacturer_Part_Number MPXV5100DP; Mouser Part Number 841-MPXV5100DP
J1, J7: USB_B_Micro; USB_Micro-B_GCT_USB3076-30-A
J2: Micro_SD_Card; microSD_HC_Hirose_DM3BT-DSF-PEJS
J3, J4, J5, J6, J8, J9, J11: Screw_Terminal_01x02; TerminalBlock_bornier-2_P5.08mm
J10: U.FL-R-SMT-1_10_; RYLR993 Antenna connector
L1: 1.8nH; L_0805_2012Metric
L2, L3: 47nH; L_0805_2012Metric
R1: 22; R_0805_2012Metric
R2, R7, R8, R10, R12: 220; R_0805_2012Metric
R3, R9: 10k; R_0805_2012Metric
R4, R5: 4.7k; R_0805_2012Metric
R6: 0; R_0805_2012Metric
SW1, SW2: SW_Push; SW_Tactile_SPST_NO_Straight_CK_PTS636Sx25SMTRLFS
TP1, TP2, TP3, TP8, TP12, TP14, TP16, TP17, TP18: TestPoint; TestPoint_Pad_D1.0mm
U1, U12: AMS1117-3.3; SOT-223-3_TabPin2
U2: IIM-42653; IIM-42652_TDK; PARTREV 1.1
U3, U13: D3V3XA4B10LP; Diodes_UDFN-10_1.0x2.5mm_P0.5mm
U4: LPS22HHTR_3
U5: ESP32-S3-WROOM-1U-N16R8; ESP32-S3-WROOM-1U
U6: M20050 GPS
U7, U10: IRLR7843TRPBF
U8: AMS1117-5.0; SOT-223-3_TabPin2
U9: RYLR993
U15: ESP32-S3-MINI-1U; ESP32-S2-MINI-1U

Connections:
3.3V_OUT: C1.1, C6.1, C7.2, C8.1, C9.1, C10.1, C11.2, C14.1, C15.1, C16.1, C31.1, C32.1, D5.1 (K), D7.1 (K), J2.4 (VDD), R3.1, R4.1, R5.2, TP3.1, TP8.1, U2.5 (VDDIO), U2.8 (VDD), U4.1 (Vdd_IO), U4.10 (VDD), U5.2 (3V3), U6.8 (VCC), U6.12 (BV), U9.12 (VBAT), U9.13 (VDD), U9.14 (VDD), U9.15 (VDD), U15.3 (3V3)
3.7Vin: C24.1, C26.1, J6.2, TP14.1, U12.3 (VI)
5V_USB: C2.1, C3.1, J1.1 (VBUS), TP1.1, U1.3 (VI), U3.4, U3.7 (NC)
5V_USB2: J7.1 (VBUS), U13.4
5Vout_Cam: C21.1, C22.1, IC1.2 (VS), IC2.2 (VS), J11.2, R7.1, TP18.1, U8.2 (VO)
7.4Vin_Cam: C19.1, C20.1, J9.2, TP16.1, U8.3 (VI)
Antenna: J10.2 (SIG), U9.43 (RF)
DRG: U5.6 (IO6), U7.1 (Gate)
GND: C1.2, C2.2, C3.2, C4.2, C5.2, C6.2, C7.1, C8.2, C9.2, C10.2, C11.1, C12.1, C14.2, C15.2, C16.2, C17.2, C18.1, C19.2, C20.2, C21.2, C22.2, C23.1, C24.2, C25.1, C26.2, C28.2, C30.2, C31.2, C32.2, D1.1 (K), D2.1 (K), D6.1 (K), H1.1, H2.1, H3.1, H4.1, IC1.3 (GND), IC2.3 (GND), J1.5 (GND), J1.6 (Shield), J2.6 (VSS), J3.2, J6.1, J7.5 (GND), J7.6 (Shield), J8.1, J9.1, J10.1 (GND), J10.3 (GND), J11.1, L1.2, R6.2, R9.1, SW1.1, SW2.1, TP2.1, TP12.1, TP17.1, U1.1 (GND), U2.6 (GND), U2.7 (RESV), U3.3 (VSS), U3.8 (VSS), U4.3 (GND), U4.8 (GND), U4.9 (GND), U5.1 (GND), U5.40 (GND), U5.41 (GND), U6.2 (GND), U6.3 (GND), U6.5 (GND), U6.7 (GND), U6.9 (GND), U6.15 (GND), U6.16 (GND), U6.17 (GND), U6.19 (GND), U6.22 (GND), U6.23 (GND), U6.24 (GND), U6.25 (GND), U6.27 (GND), U7.2 (Source), U8.1 (GND), U9.1 (GND), U9.7 (GND), U9.8 (GND), U9.9 (GND), U9.10 (GND), U9.11 (GND), U9.22 (GND), U9.23 (GND), U9.28 (GND), U9.32 (GND), U9.41 (GND), U9.42 (GND), U9.44 (GND), U10.2 (Source), U12.1 (GND), U13.3 (VSS), U13.8 (VSS), U15.1 (GND), U15.2 (GND), U15.42 (GND), U15.43 (GND), U15.46 (GND), U15.47 (GND), U15.48 (GND), U15.49 (GND), U15.50 (GND), U15.51 (GND), U15.52 (GND), U15.53 (GND), U15.54 (GND), U15.55 (GND), U15.56 (GND), U15.57 (GND), U15.58 (GND), U15.59 (GND), U15.60 (GND), U15.61 (GND), U15.62 (GND), U15.63 (GND), U15.64 (GND), U15.65 (GND)
GPS_STDB: U5.38 (IO2), U6.26 (HW_S)
IMU_FSPICLK: U2.13 (AP_SCL/AP_SCLK), U5.9 (IO16)
IMU_FSPICS: U2.12 (AP_CS), U5.10 (IO17)
IMU_SDI: U2.14 (AP_SDA/AP_SDIO/AP_SDI), U5.8 (IO15)
IMU_SDO: U2.1 (AP_SDO/AP_AD0), U5.7 (IO7)
unnamed: D1.2 (A), R2.2
unnamed: D2.2 (A), R7.2
unnamed: D3.2 (A), R8.1
unnamed: D3.1 (K), J4.1
unnamed: D4.2 (A), R10.1
unnamed: D4.1 (K), J5.1
unnamed: C4.1, C5.1, D5.2 (A), R2.1, U1.2 (VO)
unnamed: D6.2 (A), R12.2
unnamed: C28.1, C30.1, D7.2 (A), R12.1, U12.2 (VO)
unnamed: J2.7 (DAT0), R1.2
unnamed: J3.1, R8.2, R10.2
unnamed: J4.2, U7.3 (Drain)
unnamed: J5.2, U10.3 (Drain)
unnamed: C13.1, U6.4 (ANT_OUT)
unnamed: R6.1, U6.1 (AT1)
unnamed: L1.1, U6.28 (AT2)
unnamed: C13.2, U6.6 (RF_IN)
unnamed: L3.1, U6.21 (RX)
unnamed: L2.1, U6.20 (TX)
unnamed: R9.2, U9.6 (PH3)
P_SCL: R5.1, U4.2 (SCL), U5.23 (IO21)
P_SDA: R4.2, U4.4 (SDA), U5.22 (IO14)
Pitot_1: IC1.4 (VOUT), U15.9 (IO5)
Pitot_2: IC2.4 (VOUT), U15.19 (IO15)
RST: C12.2, C23.2, R3.2, SW1.2, U5.3 (EN)
RST_1: C25.2, SW2.2, U15.45 (EN)
RX_GPS: C18.2, L3.2, U5.37 (TXD0)
RYLR_RX: U5.5 (IO5), U9.40 (PA3/RXD)
RYLR_TX: U5.4 (IO4), U9.39 (PA2/TXD)
S3_COMMS_SCL: U5.32 (IO39), U15.6 (IO2)
S3_COMMS_SDA: U5.33 (IO40), U15.7 (IO3)
SD_CLK: J2.5 (CLK), U5.20 (IO12)
SD_CS: J2.2 (DAT3/CD), U5.18 (IO10)
SD_MISO: R1.1, U5.21 (IO13)
SD_MOSI: J2.3 (CMD), U5.19 (IO11)
Servo_PWM: J8.2, U15.15 (IO11)
TD: U5.39 (IO1), U10.1 (Gate)
TX_GPS: C17.1, L2.2, U5.36 (RXD0)
USB2_D+: J7.3 (D+), U13.2, U13.9 (NC), U15.24 (IO20)
USB2_D-: J7.2 (D-), U13.1, U13.10 (NC), U15.23 (IO19)
USB_D+: J1.3 (D+), U3.2, U3.9 (NC), U5.14 (IO20)
USB_D-: J1.2 (D-), U3.1, U3.10 (NC), U5.13 (IO19)

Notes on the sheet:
MAIN BATTERY LDO
MPXV5100DP
USB with ESD protection (S3 WROOM)
Iout(Max) = 800 mA
5V LDO for Camera and DP Sensor
Regulated 5V Terminal block for Camera
IIM-42653
PYRO BATTERY
Vidyut
DROGUE PYRO
Servo motor Terminal Block
Main batteries Terminal Block
ESP32-S3-WROOM-1U
MOUNTING HOLES
Test Points
RYLR993
TD PYRO
7.4V batteries for Cam and DP sensor
ESP32-S3-MINI-1U
Vin(max) = 12V
3.3V LDO_USB
USB with ESD protection (S3 MINI)
LPS22HHTR
GPS MODULE
SD-card connector

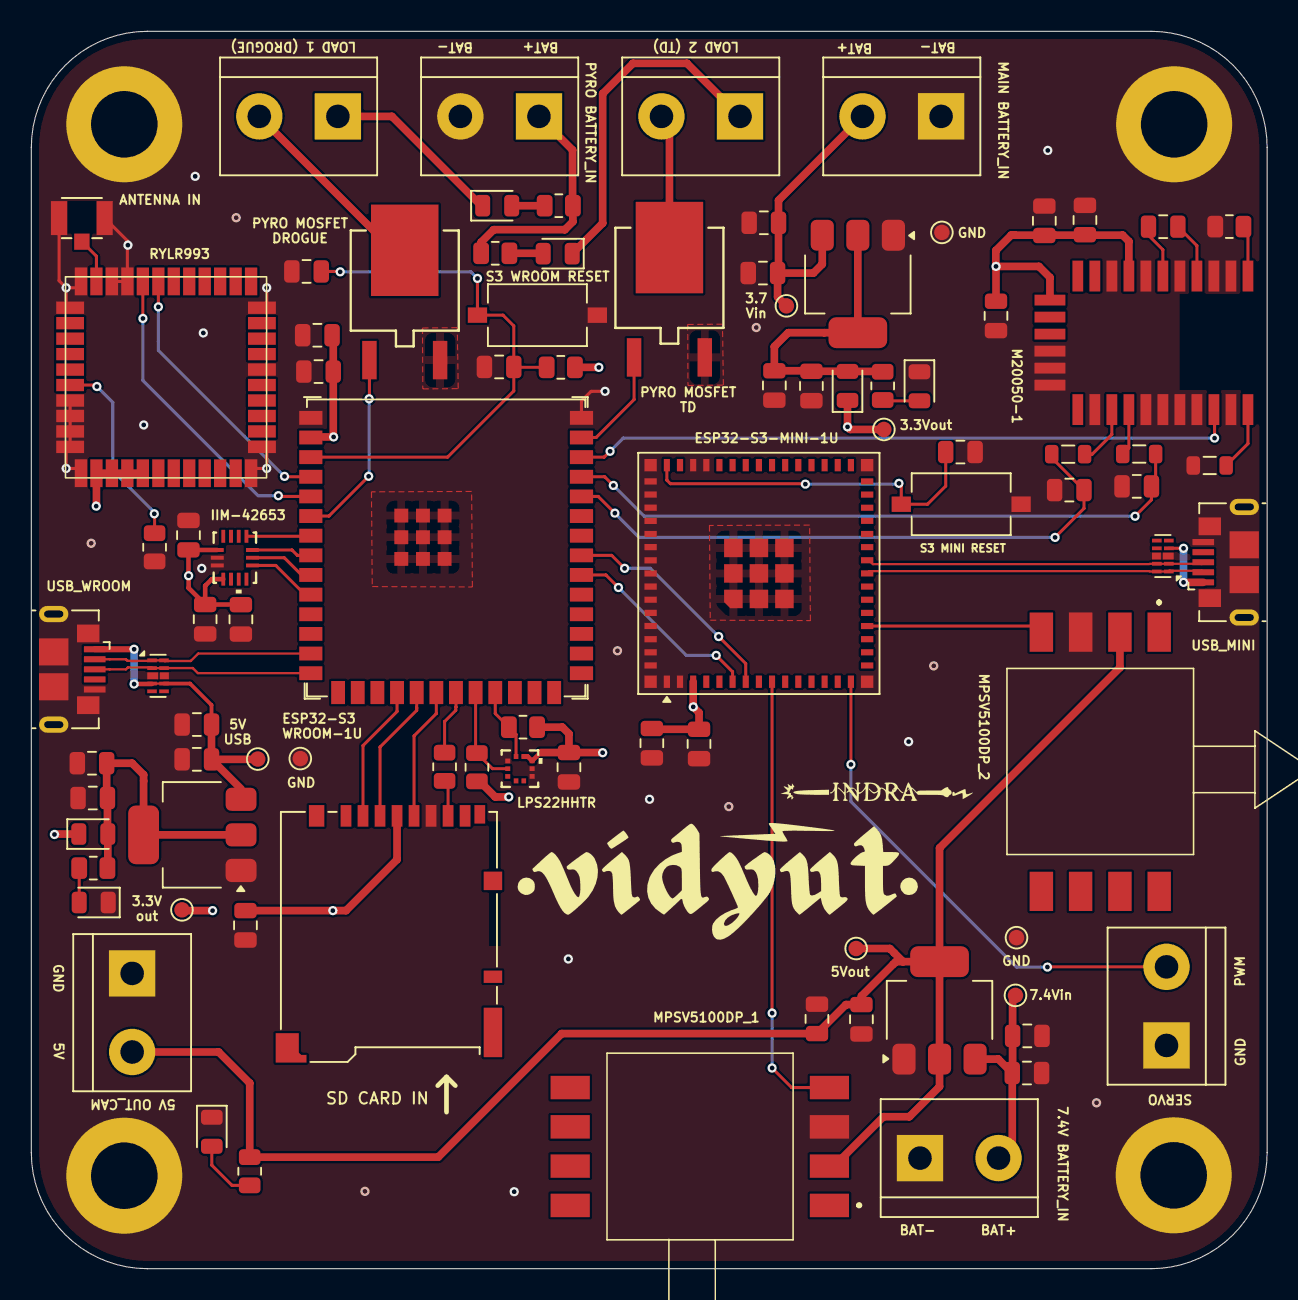
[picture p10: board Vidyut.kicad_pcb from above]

Board: 4 copper layers, 79.9 x 80.0 mm, 92 parts (0 on the bottom side), 56 nets.

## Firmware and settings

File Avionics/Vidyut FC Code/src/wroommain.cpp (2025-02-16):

#include "IIM42653.h"
#include "LPS22HH.h"
#include "FuGPS.h"
#include "madgwickFilter.h"
#include "iir.h"
#include "RYLR993.h"
#include <cmath>
#include "freertos/FreeRTOS.h"
#include "freertos/task.h"
#include <Wire.h>

// Pin Definitions
#define RYLR_RX     1
#define RYLR_TX     2
#define SD_SCK      3
#define SD_MOSI     4
#define SD_MISO     5
#define SD_SS       6
#define IIM_SCK     7
#define IIM_MOSI    8
#define IIM_MISO    9
#define IIM_SS      10
#define LPS_SDA     11
#define LPS_SCL     12
#define GNSS_RX     13
#define GNSS_TX     14
#define MINI_SDA    15
#define MINI_SCL    16

// Constants
#define ALPHA -0.0065f
#define R 287.06f
#define g0 9.80665f
#define T_1 299.45f
#define P_1 100483.97f

#define PRESSURE_BUFFER_SIZE 15
#define MINI_I2C_ADDR 0x08

// Structure for pressure buffer
typedef struct {
    float *buffer;
    int size;
    int head;
} PressureBuffer;

PressureBuffer* pb;

// Structure for Euler angles
typedef struct {
    float roll;
    float pitch;
    float yaw;
} EulerAngles;

EulerAngles orient;

// Enum for different flight stages
typedef enum {
    STANDBY,
    LAUNCH,
    COASTING,
    APOGEE,
    MAIN,
    RECOVERY
} FlightStage;

// Global variables
FlightStage currStage = STANDBY;

// Declare two I2C instances
TwoWire IIM_I2C = TwoWire(0); // I2C port 0
TwoWire MINI_I2C = TwoWire(1); // I2C port 1

IIM42653 imu;
LPS22HH pres;
RYLR993 RLYR(Serial1, RYLR_RX, RYLR_TX, 57600);
Iir::Butterworth::LowPass<2> butterworthFilter;
Storage store;
FuGPS gps;

const float cutoffFrequency = 2.0f;
const float sampleRate = 1000.0f;

IIM42653_axis_t accel_data;
IIM42653_axis_t gyro_data;
float pressure, temperature;
float altAGL = 0.0;
float filteredPressure = 0.0;
bool apogeeByPressure = false;
bool apogeeByOrientation = false;

// Task handles
TaskHandle_t dataCollectionTaskHandle;
TaskHandle_t computationTaskHandle;

// Function prototypes
void dataCollectionTask(void *parameter);
void computationTask(void *parameter);
bool apogeeDetected();

// Transitions the flight state based on sensor data and conditions
void stateTransition() {
    switch (currStage) {
        case STANDBY:
            if (accel_data.y > 10) currStage = LAUNCH;
            store.storeToSD();
            break;
        case LAUNCH:
            if (accel_data.y < 0) currStage = COASTING;
            store.storeToSD();
            break;
        case COASTING:
            if (apogeeDetected()) currStage = APOGEE;
            digitalWrite(DROGUE, HIGH);
            store.storeToSD();
            break;
        case APOGEE:
            if (altAGL < 457) currStage = MAIN;
            digitalWrite(TD, HIGH);
            digitalWrite(DROGUE, LOW);
            store.storeToSD();
            break;
        case MAIN:
            if (gyro_data.x == 0 && gyro_data.y == 0 && gyro_data.z == 0) currStage = RECOVERY;
            digitalWrite(TD, LOW);
            store.storeToSD();
            break;
        case RECOVERY:
            break;
    }
}

// Retrieves GPS data from the serial port and encodes it
void getGPSData() {
    while (Serial2.available()) {
        char c = Serial2.read();
        gps.encode(c);
    }
}

// Retrieves accelerometer and gyroscope data from the IMU
void getIMUData() {
    imu.get_accel_data(&accel_data);
    imu.get_gyro_data(&gyro_data);
}

// Retrieves pressure and temperature data from the pressure sensor
void getPressureData() {
    pressure = pres.readPressure();
    temperature = pres.readTemperature();
}

// Calculates the altitude above ground level (AGL) using pressure data
void calculateAltitude() {
    altAGL = (T_1 / ALPHA) * (pow((filteredPressure / P_1), -((ALPHA * R) / g0)) - 1);
}

// Filters the pressure data using a Butterworth filter and adds it to a buffer
void filterPressure() {
    filteredPressure = butterworthFilter.filter(pressure);
    addReading(filteredPressure);
}

// Detects if apogee has been reached based on pressure and orientation
bool apogeeDetected() {
  if (apogeeByPressure == false && isAscending()) {
    timePressureApogee = millis();
  }

  if (isAscending()) apogeeByPressure = true;
  if ((85 <= orient.pitch && orient.pitch <= 95) || (85 <= orient.yaw && orient.yaw <= 95))
    apogeeByOrientation = true;

  return apogeeByPressure && (apogeeByOrientation || (millis() - timePressureApogee >= 3000));
}

// Initializes the pressure buffer
bool initializeBuffer() {
    pb = (PressureBuffer*)malloc(sizeof(PressureBuffer));
    pb->buffer = (float*)malloc(PRESSURE_BUFFER_SIZE * sizeof(float));
    if (!pb->buffer) {
        Serial.println("Failed to allocate memory for pressure buffer");
        return false;
    }
    pb->size = 0;
    pb->head = 0;
    return true;
}

// Adds a pressure reading to the pressure buffer
void addReading(float pressure) {
    if (!pb || !pb->buffer) {
        Serial.println("Error: Buffer not initialized. Call initializeBuffer() first.");
        return;
    }
    int index = (pb->head + pb->size) % PRESSURE_BUFFER_SIZE;
    pb->buffer[index] = pressure;
    if (pb->size == PRESSURE_BUFFER_SIZE) {
        pb->head = (pb->head + 1) % PRESSURE_BUFFER_SIZE;
    } else {
        pb->size++;
    }
}

// Determines if the pressure readings are ascending in the buffer
bool isAscending() {
    if (pb->size <= 1) {
        return true;
    }
    int prevIndex = pb->head;
    for (int i = 1; i < pb->size; ++i) {
        int currIndex = (pb->head + i) % PRESSURE_BUFFER_SIZE;
        if (pb->buffer[currIndex] < pb->buffer[prevIndex]) {
            return false;
        }
        prevIndex = currIndex;
    }
    return true;
}

// Calibrates the initial orientation using accelerometer data
void calibrateInitialOrientation() {
  float sum_ax = 0.0f, sum_ay = 0.0f, sum_az = 0.0f;
  int count = 0;

  while (count < num) {
    getIMUData();
    sum_ax += accel_data.x;
    sum_ay += accel_data.y;
    sum_az += accel_data.z;
    count++;
  }

  // Calculate average acceleration values
  float avg_ax = sum_ax / num;
  float avg_ay = sum_ay / num;
  float avg_az = sum_az / num;

  // Calculate initial roll and pitch (assuming X-axis is along the rocket axis)
  float initial_roll  = atan2f(avg_ay, avg_az); // Roll around X-axis
  float initial_pitch = atan2f(-avg_ax, sqrtf(avg_ay * avg_ay + avg_az * avg_az)); // Pitch around Y-axis
  initial_yaw_offset = 0.0f; //Initialize to 0

  // Create a quaternion representing the initial orientation
  struct quaternion initial_q;
  float cy = cosf(initial_yaw_offset * 0.5f);
  float sy = sinf(initial_yaw_offset * 0.5f);
  float cp = cosf(initial_pitch * 0.5f);
  float sp = sinf(initial_pitch * 0.5f);
  float cr = cosf(initial_roll * 0.5f);
  float sr = sinf(initial_roll * 0.5f);

  initial_q.q1 = cr * cp * cy + sr * sp * sy;
  initial_q.q2 = sr * cp * cy - cr * sp * sy;
  initial_q.q3 = cr * sp * cy + sr * cp * sy;
  initial_q.q4 = cr * cp * sy - sr * sp * cy;

  // Normalize the quaternion
  quat_Normalization(&initial_q);

  // Set the initial quaternion estimate (q_est)
  q_est = initial_q;
}

// Calculates vertical acceleration based on Euler angles and accelerometer data
float calculateVerticalAccel(float roll, float pitch, float yaw, float x_accel, float y_accel, float z_accel) {
 // Create rotation matrix (ZYX convention)
  float cosRoll = cosf(roll);
  float sinRoll = sinf(roll);
  float cosPitch = cosf(pitch);
  float sinPitch = sinf(pitch);
  float cosYaw = cosf(yaw);
  float sinYaw = sinf(yaw);... //Rotation Matrix from body frame to world frame (ZYX convention)
  float rotationMatrix[3][3] = {
      {cosPitch * cosYaw, cosPitch * sinYaw, -sinPitch},
      {sinRoll * sinPitch * cosYaw - cosRoll * sinYaw, sinRoll * sinPitch * sinYaw + cosRoll * cosYaw, sinRoll * cosPitch},
      {cosRoll * sinPitch * cosYaw + sinRoll * sinYaw, cosRoll * sinPitch * sinYaw - sinRoll * cosYaw, cosRoll * cosPitch}
  };

  // Transform acceleration vector from body frame to world frame
  float world_z_accel = rotationMatrix[2][0] * x_accel + rotationMatrix[2][1] * y_accel + rotationMatrix[2][2] * z_accel;
  return world_z_accel;
}

// Initializes the RYLR module with a given address
void RYLRinit(uint16_t add) {
  RLYR.begin();
  RLYR.setAddress(add);
}

// Sends data to the Mini via I2C
void sendDataToMini() {
    char dataBuffer[50]; // Buffer to hold formatted data string
    snprintf(dataBuffer, sizeof(dataBuffer), "%d,%.2f,%.2f,%.2f,%.2f,%.2f,%.2f",currStage, 
             altAGL, pressure, temperature, orient.roll, orient.pitch, orient.yaw);

    MINI_I2C.beginTransmission(MINI_I2C_ADDR);
    MINI_I2C.write(dataBuffer);  // Send data as string
    MINI_I2C.endTransmission();
    
    Serial.print("Sent to Mini: ");
    Serial.println(dataBuffer);
}

// Collects sensor data and transmits it
void dataCollection() {
    getIMUData();
    getPressureData();
    store.storeData(pressure, accel_data.x, accel_data.y, accel_data.z, gyro_data.x, gyro_data.y, gyro_data.z, temperature);
    getGPSData();
    String data = String(currStage) + ";" + String(pressure) + ";" + String(accel_data.x) + ";" + String(accel_data.y) + ";" + String(accel_data.z)+ ";" + String(gyro_data.x) + ";" + String(gyro_data.y) + ";" + String(gyro_data.z) + ";" + String(gps.longitude) + ";" + String(gps.latitude);
    RYLR.sendMessage(0,data);
    vTaskDelay(pdMS_TO_TICKS(10));
}

// Task running on core 0 for data collection and transmission
void core0Task(void *parameter) {
    while (1) {
        switch(currStage) {
            case STANDBY:
            break;
            case RECOVERY:
            getGPSData();
            RYLR.sendMessage(String(gps.latitude) + "," + String(gps.longitude));
            break;
            default:
            dataCollection();
            sendDataToMini();
        }
    }
}

// Task running on core 1 for computation
void core1Task(void *parameter) {
    while (1) {
        switch(currStage) {
            case STANDBY:
            break;
            case RECOVERY:
            break;
            default:
            computationTask();
        }
    }
}

// Performs computation tasks such as filtering pressure, calculating altitude, and transitioning states
void computationTask(void *parameter) {
    filterPressure();
    calculateAltitude();
    stateTransition();
}

// Initializes the sensors, modules, and FreeRTOS tasks
void setup() {
    Serial.begin(115200, SERIAL_8N1, RX_PIN, TX_PIN);

    // Initialize I2C instances
    IIM_I2C.begin(IIM_SDA, IIM_SCL, 100000); // SDA, SCL, clock frequency
    MINI_I2C.begin(MINI_SDA, MINI_SCL, 100000);

    // Initialize IMU with the dedicated I2C port
    if (!imu.begin(IIM_I2C, IIM42653_SET_DEV_ADDR)) {
        Serial.println("Failed to initialize IIM42653!");
        while (1);
    }
    Serial.println("IIM42653 initialized successfully!");
    imu.accelerometer_enable();
    imu.gyroscope_enable();
    calibrateInitialOrientation();

    if (!pres.begin()) {
        Serial.println("Failed to initialize LPS22HH!");
        while (1);
    }
    Serial.println("LPS22HH initialized successfully!");
    pres.setODR(75);
    pres.calibrateSensor();

    RYLRinit(56);
    Serial2.begin(9600, SERIAL_8N1, GNSS_RX, GNSS_TX);

    butterworthFilter.setup(sampleRate, cutoffFrequency);
    initializeBuffer();
    store.begin();
    
    // Create FreeRTOS tasks for dual-core execution
    xTaskCreatePinnedToCore(core0Task, "Data Collection", 4096, NULL, 1, &dataCollectionTaskHandle, 0);
    xTaskCreatePinnedToCore(core1Task, "Computation", 4096, NULL, 1, &computationTaskHandle, 1);
}

// The main loop (empty)
void loop() {
}

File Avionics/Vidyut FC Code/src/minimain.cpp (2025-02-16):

#include <Wire.h>
#include <EEPROM.h>
#include <ESP32Servo.h>
#include "Controls.h"

#define GAMMA 1.4f
#define R 287.06f

#define I2C_SLAVE_ADDR 0x08  // I2C address of ESP32-S3-MINI
#define PITOT1_PIN 13       // Analog pin for sensor 1
#define PITOT2_PIN 14       // Analog pin for sensor 2
#define EEPROM_SIZE 512      // Max EEPROM size for storing data

const int servoPin = 15;
const int EXTEND_ANGLE = 90;
const int RETRACT_ANGLE = 0;

typedef enum {
    STANDBY,
    LAUNCH,
    COASTING,
    APOGEE,
    MAIN,
    RECOVERY
} FlightStage;

FlightStage currStage = STANDBY;
Servo airbrakeServo;

int pitot1_ADC = 0;
int pitot2_ADC = 0;
float pitot1_pressure = 0.0;
float pitot2_pressure = 0.0;
char received_data[64];
float altitude = 0.0;
float velocity = 0.0;
float temp = 0.0;
float staticPressure = 0.0;
float dynamicPressure = 0.0;
float euler_angles[3] = {0.0, 0.0, 0.0};
int eeprom_address = 0;
float apogee = 3048.0;

float convToPressure(int ADC) {
    return (ADC * 5000 / (45 * 4095)) * 1000; // Convert ADC value to pressure (Pa)
}

float calculateVelocity() {
    float a = sqrt(GAMMA * R * temp);
    return ((2 * a * a) / (GAMMA - 1)) * (pow(((dynamicPressure / staticPressure) + 1), (1 - (1 / GAMMA))) - 1);
}

void receiveEvent(int bytes) {
    int i = 0;
    while (Wire.available() && i < sizeof(received_data) - 1) {
        received_data[i++] = Wire.read();
    }
    received_data[i] = '\0'; // Null terminate the string
    Serial.print("Received from Master: ");
    Serial.println(received_data);
    
    sscanf(received_data, "%d,%f,%f,%f,%f,%f,%f", &currStage, &altitude, &staticPressure, &temp, &euler_angles[0], &euler_angles[1], &euler_angles[2]);
}

void requestEvent() {
    String data = String(pitot1_pressure) + "," + String(pitot2_pressure); // Use correct variables
    Wire.write(data.c_str());
}

void storeToEEPROM() {
    EEPROM.put(eeprom_address, pitot1_pressure);
    eeprom_address += sizeof(pitot1_pressure);
    EEPROM.put(eeprom_address, pitot2_pressure);
    eeprom_address += sizeof(pitot2_pressure);
    EEPROM.put(eeprom_address, altitude);
    eeprom_address += sizeof(altitude);
    
    if (eeprom_address >= EEPROM_SIZE) eeprom_address = 0; // Loop back if EEPROM is full
    EEPROM.commit();
}

void setup() {
    Serial.begin(115200);
    Wire.begin(I2C_SLAVE_ADDR); // Start I2C as a slave
    Wire.onReceive(receiveEvent);
    Wire.onRequest(requestEvent);
    
    analogReadResolution(12);
    pinMode(PITOT1_PIN, INPUT);
    pinMode(PITOT2_PIN, INPUT);
    
    airbrakeServo.attach(servoPin, 500, 2500); // Servo pulse width range is 500 to 2500 µs
    airbrakeServo.write(RETRACT_ANGLE); // Initial position at RETRACT_ANGLE
    EEPROM.begin(EEPROM_SIZE); // Initialize EEPROM only once
}

void loop() {
    pitot1_ADC = analogRead(PITOT1_PIN);
    pitot2_ADC = analogRead(PITOT2_PIN);
    
    pitot1_pressure = convToPressure(pitot1_ADC);
    pitot2_pressure = convToPressure(pitot2_ADC);
    
    dynamicPressure = (pitot1_pressure + pitot2_pressure) / 2.0;

    velocity = calculateVelocity();

    apogee = predictApogee(velocity, apogee);
    if (altitude > 1981 && currStage == COASTING) controlAirbrakes();
    
    storeToEEPROM();
    
    delay(100); // Adjust delay as needed
}

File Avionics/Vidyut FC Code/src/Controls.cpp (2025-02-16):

#include "Controls.h"

extern Servo airbrakeServo; // Declare external servo for airbrakes

// Extend airbrakes
void extendAirbrakes() {
    airbrakeServo.write(EXTEND_ANGLE); // Move servo to extend position
}

// Retract airbrakes
void retractAirbrakes() {
    airbrakeServo.write(RETRACT_ANGLE); // Move servo to retract position
}

// Integrate velocity to calculate aerodynamic drag
float intV(float vel) {
    return (2 * DRY_MASS) / FRONTAL_AREA * log(vel);
}

// Integrate displacement for aerodynamic calculations
float intS(float s) {
    return p1 * pow(s, 3) / 3 + p2 * pow(s, 2) / 2 + p3 * s;
}

// Calculate position using inverse function based on displacement
float inverseFunc(float s) {
    float part1 = s / (2 * x) - (y * y * y) / (27 * x * x * x) + (y * z) / (6 * x * x);
    float part2 = (y * y) / (9 * x * x) - z / (3 * x);

    float intTerm = sqrt(part1 * part1 - part2 * part2 * part2);
    float sigma1 = pow((intTerm + part1), (1.0 / 3.0));

    return (part2 / sigma1 - y / (3 * x) + sigma1);
}

// Predict the apogee based on current velocity and altitude
float predictApogee(float vel, float alt) {
    float apogeeFunc = intV(vel) - intV(0) + intS(alt);
    return inverseFunc(apogeeFunc);
}

// Control airbrakes based on predicted apogee
void controlAirbrakes() {
    const float APOGEE_THRESHOLD = 10100 * 0.3048; // Convert feet to meters
    if (predictApogee() > APOGEE_THRESHOLD) {
        extendAirbrakes(); // Deploy airbrakes if above threshold
    } else {
        retractAirbrakes(); // Retract airbrakes if below threshold
    }
}

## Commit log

2025-02-16 Added Vidyut code files
    [no_hopes_l.csv]
2025-02-18 Renamed Folder
    [no_hopes_l.csv]
2025-02-19 Create Vidyut PCB
2025-02-19 Added FInal Report Supporting Files
    [Cyclohexane-B_Cu.gbr, Cyclohexane-B_Mask.gbr, Cyclohexane-B_Paste.gbr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]
2025-03-07 Relocated PCB files
